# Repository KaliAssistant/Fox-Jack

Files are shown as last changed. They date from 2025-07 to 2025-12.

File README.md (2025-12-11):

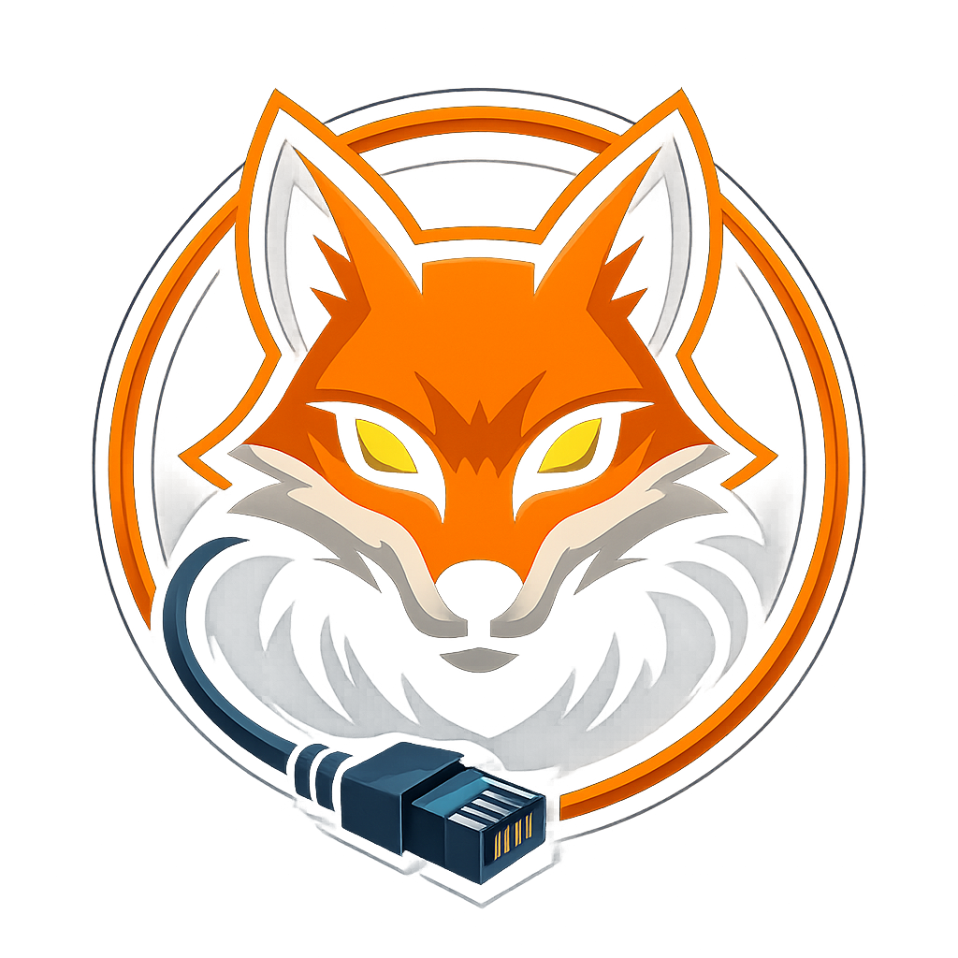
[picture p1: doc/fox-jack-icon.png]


# Fox-Jack
> Portable social-engineering LAN tool for automated payloads and wired audits — based on Luckfox Pico Max

## About

**Fox-Jack** is a low-cost, DIY social engineering LAN implant inspired by the Hak5 SharkJack.  
Designed for payload delivery, opportunistic wired auditing, and SE engagements, it features DIP-switch mode control, RGB LED feedback, and USB gadget interfaces — all powered by the **Luckfox Pico Max (RV1106G3)**.

### Features

* USB gadget function: **RNDIS** over USB
* 100 Mbps onboard **GMAC** Ethernet
* Based on **Luckfox Pico Max (RV1106G3)**
* Optional **open-source extension board PCB**:

  * 300mAh LiPo battery support (\~1–2hr uptime, longer with bigger battery)
  * **NeoPixel RGB LED** status indicator
  * **2-position DIP switch** to select payloads
* Optional **3D printable cases**
* Rootfs: **Buildroot**
* Boot: **SD card**
* U-Boot: **Luckfox official SDK**

---

## Repository Contents

* 🧰 **Luckfox Pico Official SDK**
* 🔨 **Image build scripts**
* 🧱 **3D-printable case designs**
* 🗒 **Optional extension board**:

  * KiCad project
  * Gerber files
  * BOM

---

## Parts List

| Item | Qty | Link |
| --- | --- | ---- |
| Luckfox Pico MAX (256 MB RAM version only) | 1 | [Amazon](https://a.co/d/7qTUaEF) |
| M2x0.4 Heat-Set Thread Insert (D3×H2.5) | 2 | [Amazon](https://a.co/d/6mJeA5C) |
| M2x0.4 Heat-Set Thread Insert (D3×H2) | 2 | [Amazon](https://a.co/d/6mJeA5C) |
| M2x0.4 Ultra-Low Head Torx Screws (3mm) | 2 | [Amazon](https://a.co/d/fiHYJ7t) |
| M2x0.4 Hex Socket Head Cap Screws (10mm) | 2 | [Amazon](https://a.co/d/4TCJOGo) |
| DIP Switch 1 Positions | 1 | [Amazon](https://a.co/d/8rEHPwg) |
| 302040 Lipo 3.7v battery | 1 | [Amazon](https://amzn.eu/d/auT4PZT) |

> [!NOTE]
> 🔧 PCB & BOM: all files in the `pcb/` directory

---

## Required Tools

* 28 AWG electrical wire
* Soldering tools:

  * Solder
  * Solder iron
  * Solder paste
  * Solder flux
  * Hot air gun (for SMD components on extension board)

---

## Fox-Jack EXT Board

#### Assembly Notes: [README](./pcb/README.md)

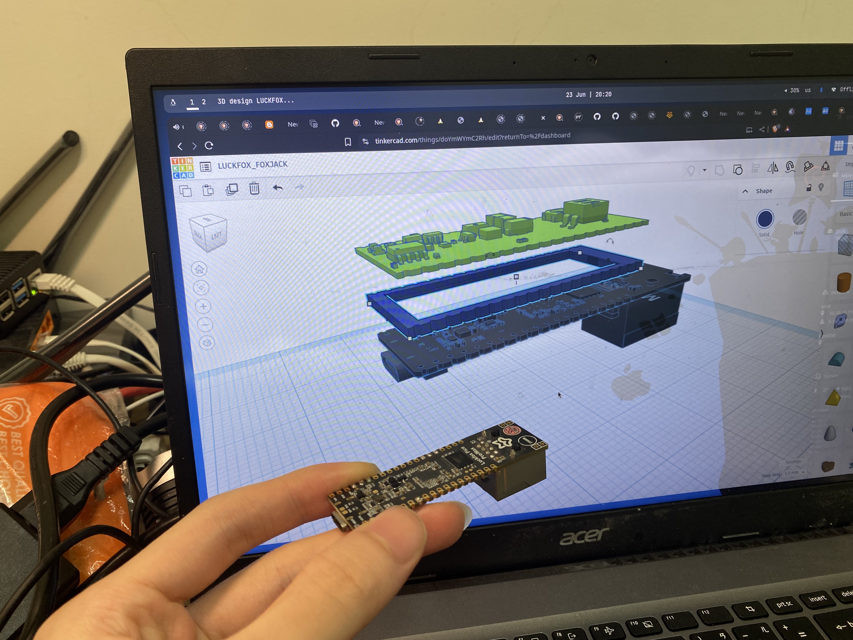
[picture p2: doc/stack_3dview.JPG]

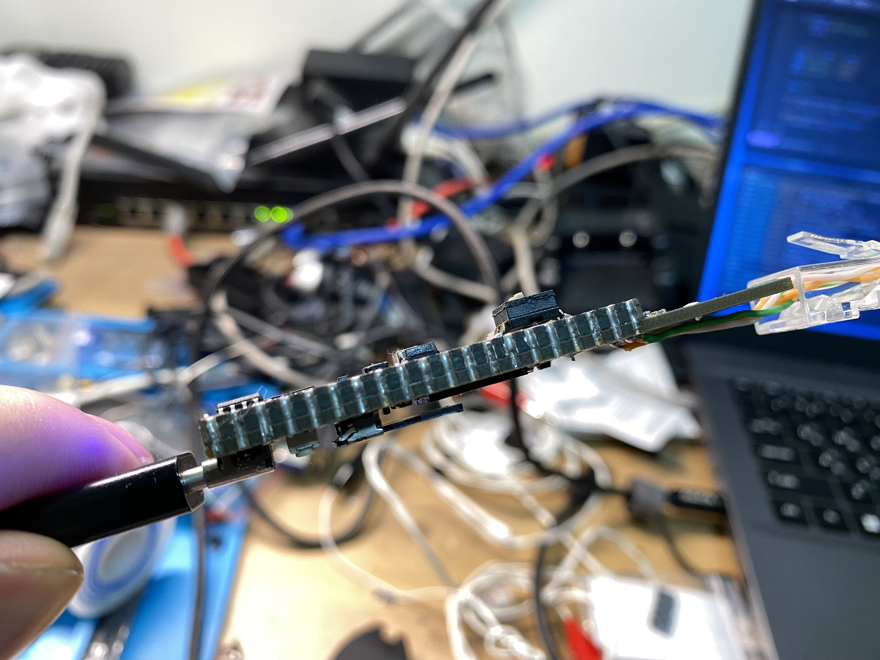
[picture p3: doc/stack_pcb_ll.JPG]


---

## 3D printable cases

#### see: [README](./3dp/README.md)

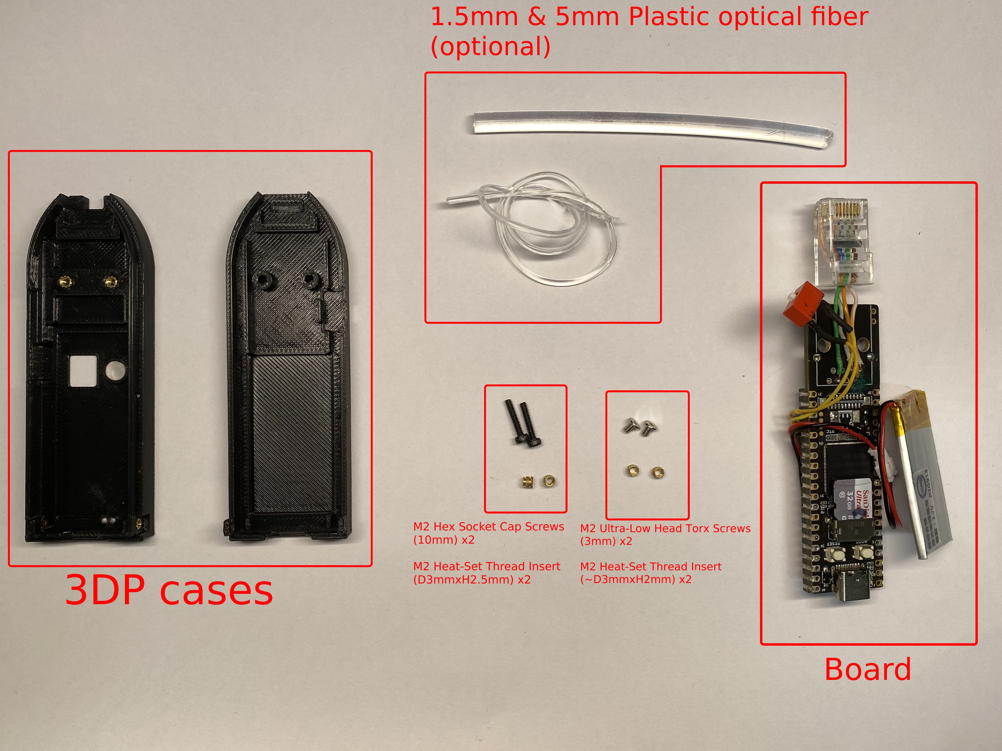
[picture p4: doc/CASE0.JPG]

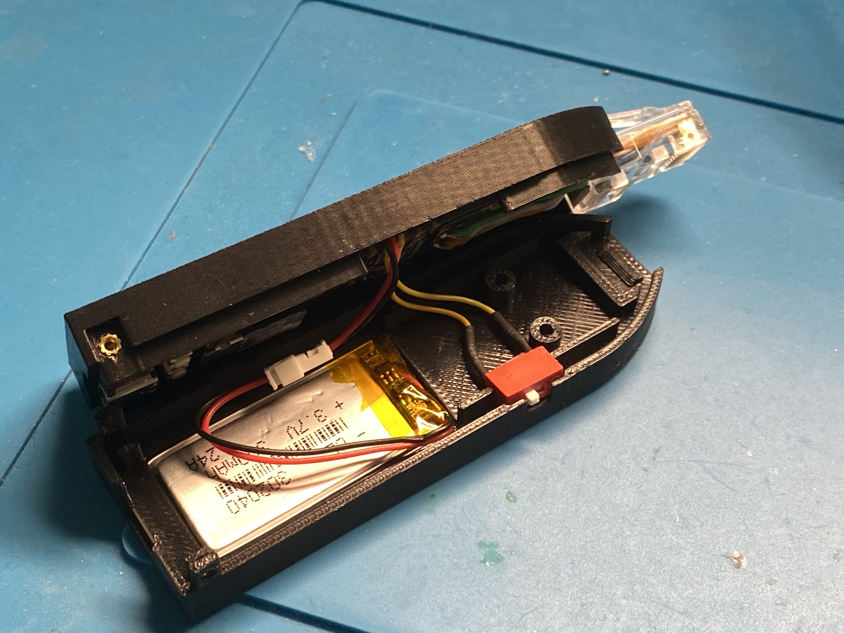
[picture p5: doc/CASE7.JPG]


---

## Build Instructions

1. Create a Debian/Ubuntu/Kali (or other Debian-based) Linux environment
   *(You can use a VM or physical machine — author uses a Debian laptop)*

2. Install required dependencies:

   ```bash
   sudo ./dep.sh
   sudo apt update
   sudo apt install -y docker.io kconfig-frontends make cmake automake autoconf libtool libtool-bin rsync
   ```
   
3. Clone the repository:

   ```bash
   git clone https://github.com/KaliAssistant/Fox-Jack.git
   ```

4. Navigate into the repo:

   ```bash
   cd Fox-Jack
   ```

5. Run the build script:

   ```bash
   sudo ./build.sh all
   ```

   You will see the SDK's *lunch menu*:

   ```
   You're building on Linux
   Lunch menu...pick the Luckfox Pico hardware version:
   [4] RV1106_Luckfox_Pico_Pro_Max
   ...
   Which would you like? [default: 0]: 4

   Lunch menu...pick the boot medium:
   [0] SD_CARD
   Which would you like? [default: 0]: 0

   Lunch menu...pick the system version:
   [0] Buildroot
   Which would you like? [default: 0]: 0
   ```

> [!NOTE]
> ✅ Just enter `4 / 0 / 0` — **only Luckfox Pico Max** is supported currently.

---

## Config Options

You can tweak build options using the following:

* **Buildroot menuconfig**:

  ```bash
  sudo ./build.sh luckfox buildrootconfig
  ```
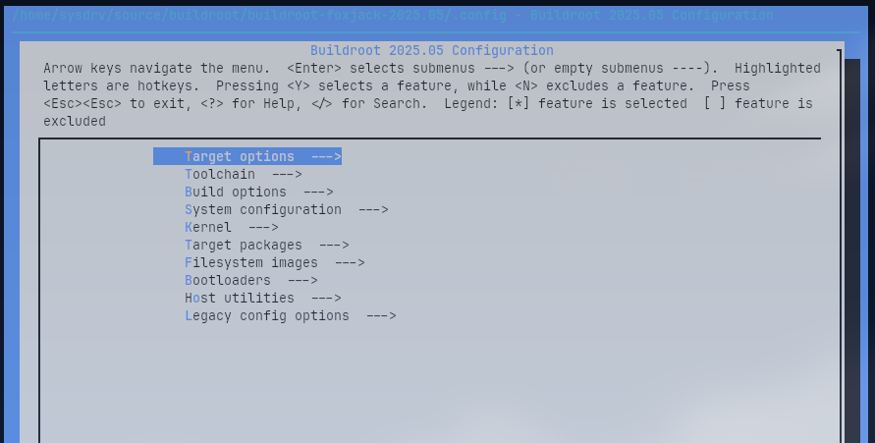
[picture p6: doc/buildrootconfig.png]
  

* **Kernel menuconfig**:

  ```bash
  sudo ./build.sh luckfox kernelconfig
  ```
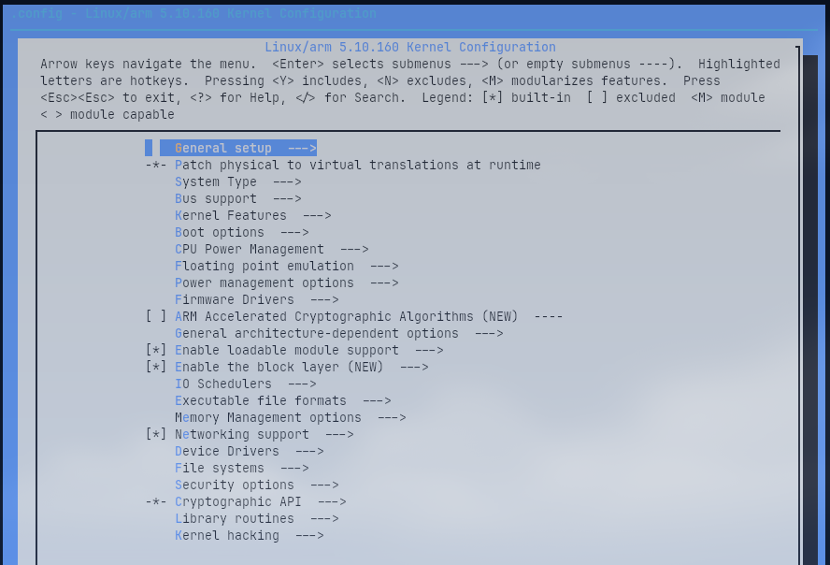
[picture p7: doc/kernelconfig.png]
  

* **Foxjack extra config (e.g., SSH key, services)**:

  ```bash
  sudo ./build.sh foxjackconfig
  ```
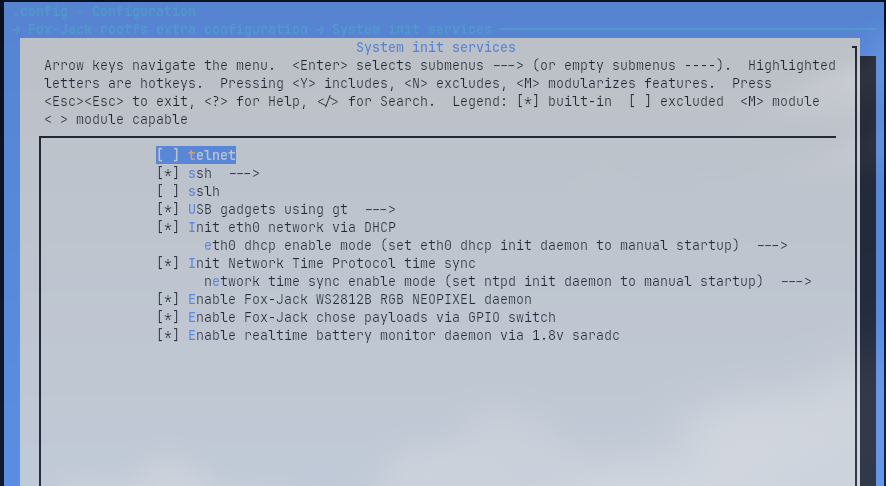
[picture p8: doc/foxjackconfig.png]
  

> [!NOTE]
> **Security Note:**
> Default root password is `foxjack`, but **SSH password login is disabled** (`PermitRootLogin prohibit-password`) for security.
> Add your public key via `foxjackconfig`.
> If you need password login, modify `/etc/ssh/sshd_config` in rootfs manually.

To access via **USB RNDIS**, make sure your host PC has a static IP in the same subnet as defined in `foxjackconfig`.

---

## Flashing to SD Card

Once the build is complete, flash the image:

```bash
sudo ./build.sh sdflash
```

You'll see:

```
WARNING: Check the SD card dev path! blkenvflash can overwrite your system drives!
Enter your SD card dev path (/dev/sxx)... >
```

> [!WARNING]
> **Be careful!** Enter the correct SD card device path to avoid overwriting your OS drive.

---

## Run Modes (Payload Selection)

Fox-Jack supports 4 modes, selected via a 2-position DIP switch:

| Mode | SW1 | SW2 | Description |
| --- | --- | --- | --- |
| 0 (debug) | 0 | 0 | Dev/debug mode |
| 1 | 1 | 0 | Payload 1 |
| 2 | 0 | 1 | Payload 2 |
| 3 | 1 | 1 | Payload 3 |

Read via GPIO:

```c
#define SW1_PIN 67  // gpio2_a3_d (pin 27)
#define SW2_PIN 66  // gpio2_a2_d (pin 26)
```

---

### Debug Mode Details

In **debug mode** (SW1=0, SW2=0):

* USB gadget provides **RNDIS Ethernet** **+ Mass Storage**
* Payloads can be edited directly from host PC
* **LOOT** (results, passwords, hashes) is saved in:

  ```
  <UMS>/loot/
  ```
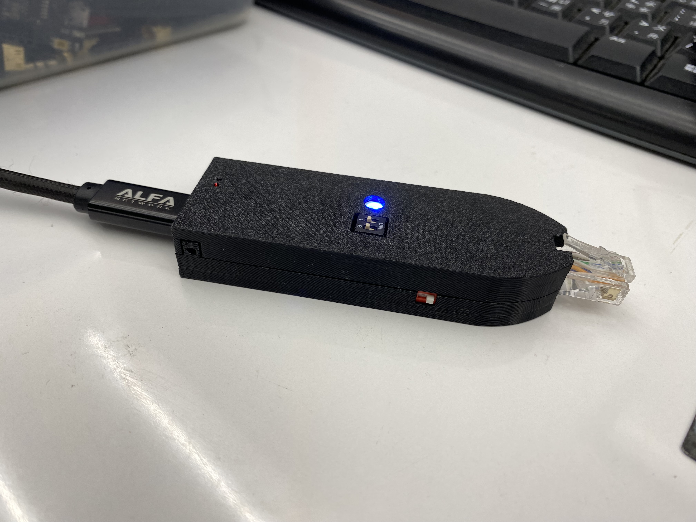
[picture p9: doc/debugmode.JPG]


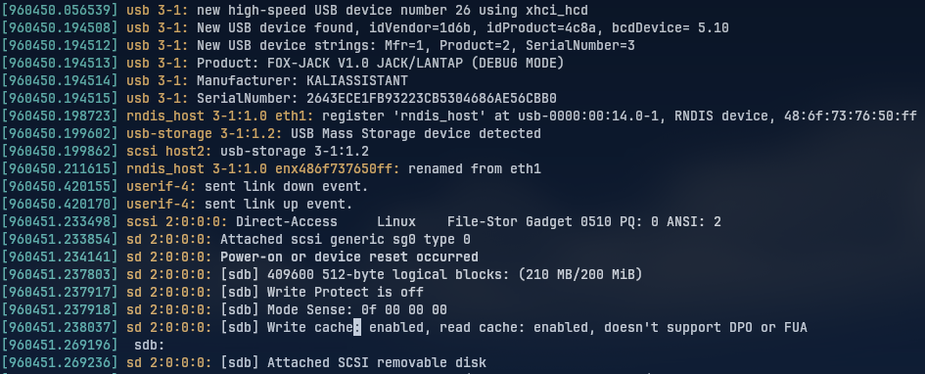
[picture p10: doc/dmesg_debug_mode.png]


---

## Payload Examples

#### see [README](./payload_examples/README.md)

Payload filenames must follow this format:

```
E????-name.payload
```

* `E????` is a 4-digit payload ID (e.g., `E0000`)
* `name` is a short, descriptive label

**Example:**

```
E0000-arp-scan.payload
```

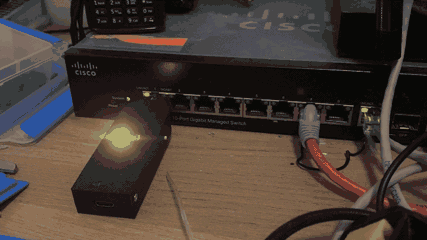
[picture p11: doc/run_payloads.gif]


---

## Disclaimer

**Fox-Jack** is intended for authorized security testing, educational, and research purposes only.  
Use of this device without explicit permission on networks or systems you do not own or have authorization to test is illegal and unethical.  
The author and contributors are not responsible for any misuse or damage caused by this tool.  
Please ensure you comply with all applicable laws and obtain proper consent before deployment.

---

## License

Fox-Jack is open-source and released under the **GNU General Public License v3.0 (GPLv3)**.
You are free to use, modify, and redistribute under the terms of this license.

See the [`LICENSE`](./LICENSE) file for full details.

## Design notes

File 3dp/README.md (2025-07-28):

#  3D Printed Case Guide – *Fox-Jack*

This folder contains the 3D printable files for the **Fox-Jack** case.

Use both **top** and **bottom** case designs with **M2 heat-set inserts** and **screws** to assemble.

---

## Step 0. Prepare These Items

| Item | Qty | Link |
| --- | --- | -----|
| M2x0.4 Heat-Set Thread Insert (D3×H2.5) |  2  | [Amazon](https://a.co/d/6mJeA5C)
| M2x0.4 Heat-Set Thread Insert (D3×H2) |  2  | [Amazon](https://a.co/d/6mJeA5C)
| M2x0.4 Ultra-Low Head Torx Screws (3mm) |  2  | [Amazon](https://a.co/d/fiHYJ7t)
| M2x0.4 Hex Socket Head Cap Screws (10mm) |  2  | [Amazon](https://a.co/d/4TCJOGo)
| Plastic optic fiber (1.2~1.5mm, optional)  |  1  | [Amazon](https://a.co/d/c6yUWJW)
| Plastic optic fiber (5mm, optional) |  1  | [Amazon](https://a.co/d/c6yUWJW)



---

##  Step 1. Print the Cases

You can use:

- Supported Materials: PLA+, PETG, ABS

> [!NOTE]
> Do **not** use **non-FDM** printers (e.g. resin printers), since heat-set inserts won’t work with those materials.

---

## Step 2. Insert Heat-Set Inserts

- You can use a soldering iron or a dedicated tool
- Gently press the inserts into place while heating

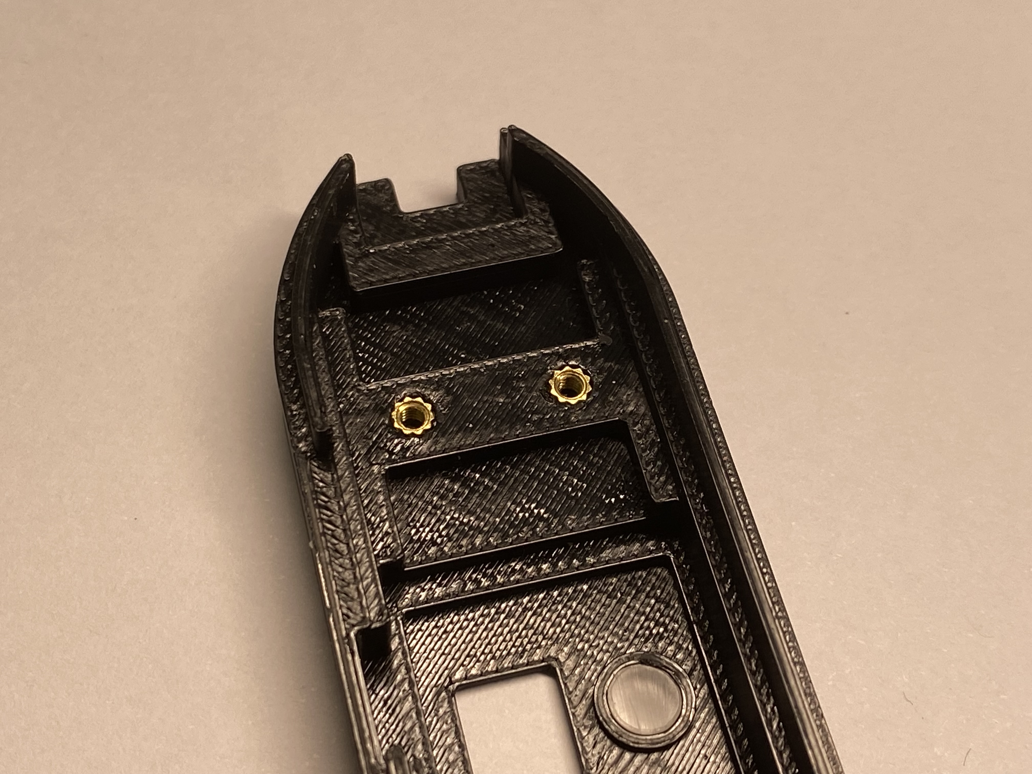
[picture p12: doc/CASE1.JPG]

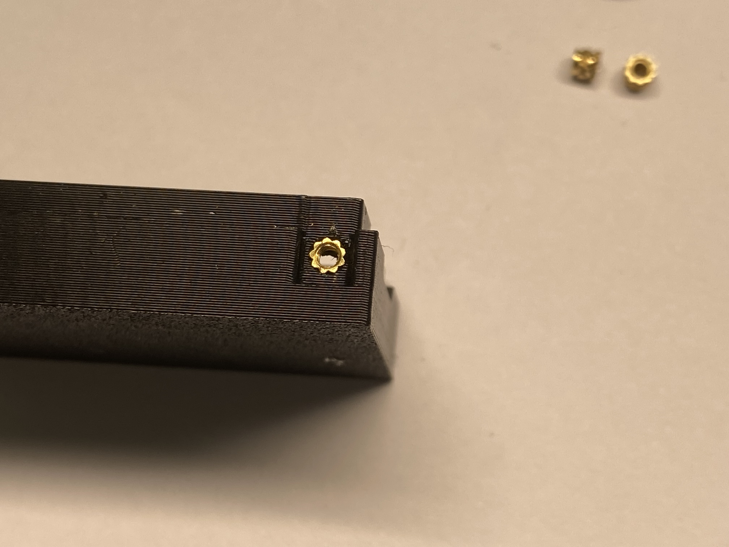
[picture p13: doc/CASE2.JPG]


---

## Step 3. Add Fiber to LED Holes (Optional, But Looks Awesome)

- Plastic fiber makes LED glow look much better
- Push fiber into LED holes

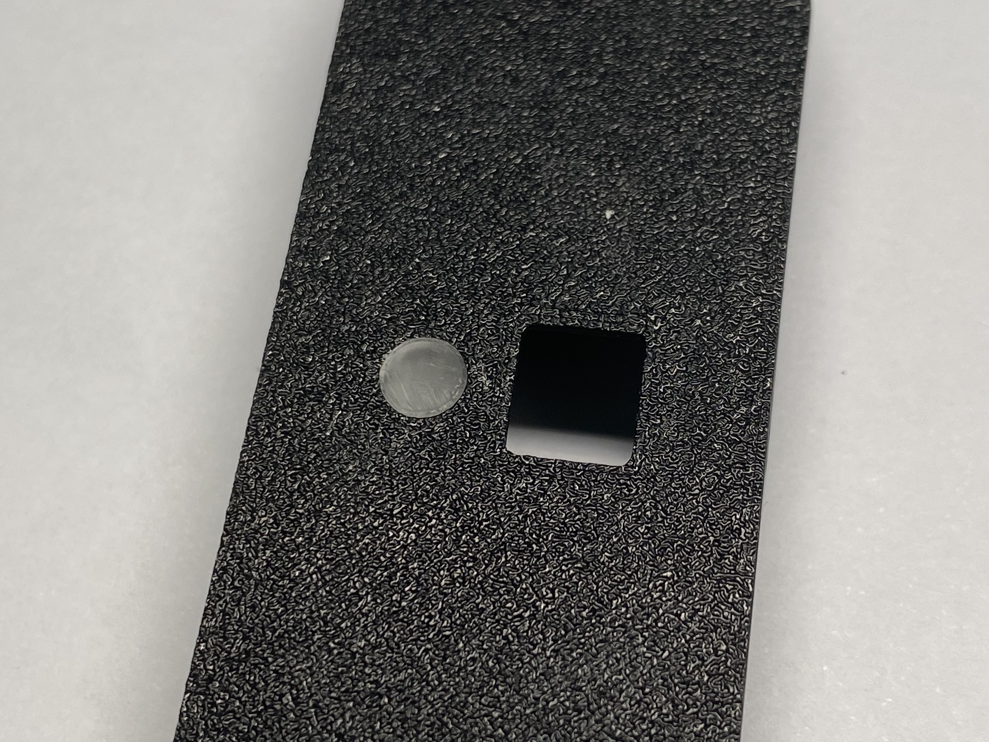
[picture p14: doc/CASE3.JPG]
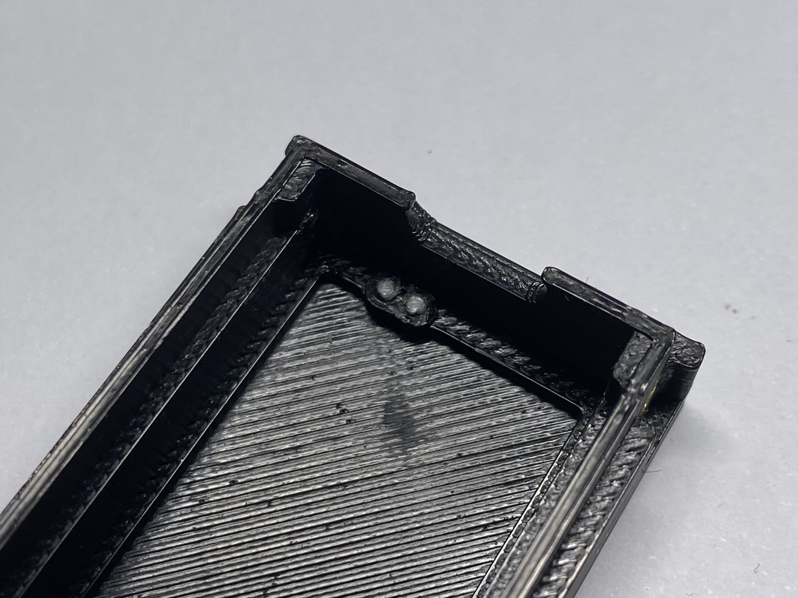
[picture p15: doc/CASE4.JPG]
 
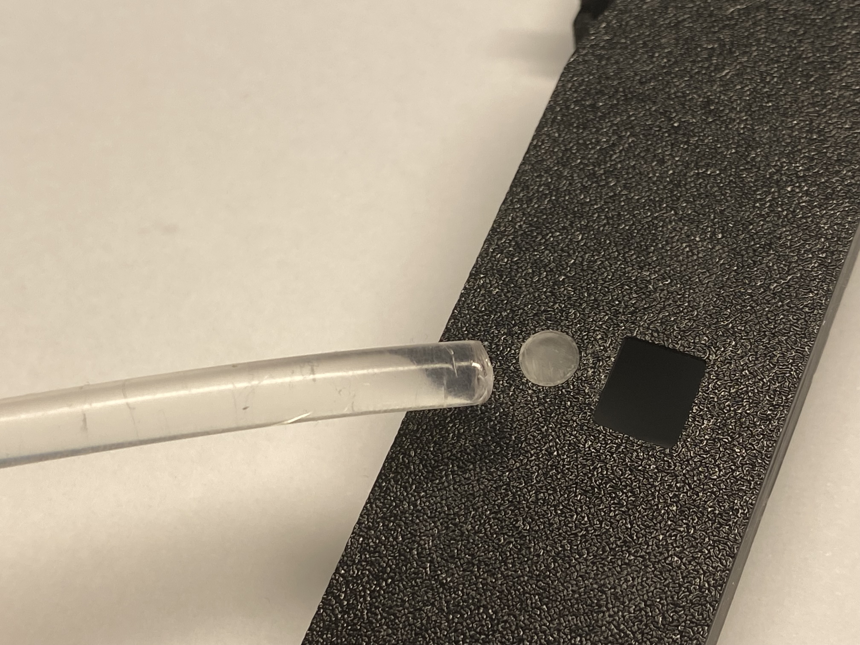
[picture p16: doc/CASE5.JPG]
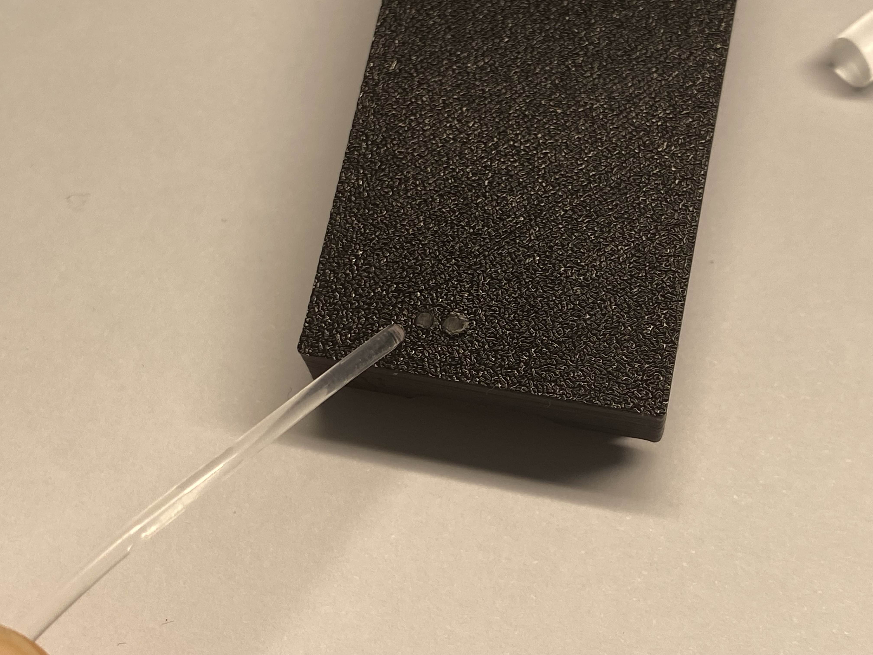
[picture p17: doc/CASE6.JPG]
 

---

## Step 4. Final Assembly

- Align top and bottom case
- Use M2 screws to secure
- Don’t overtighten


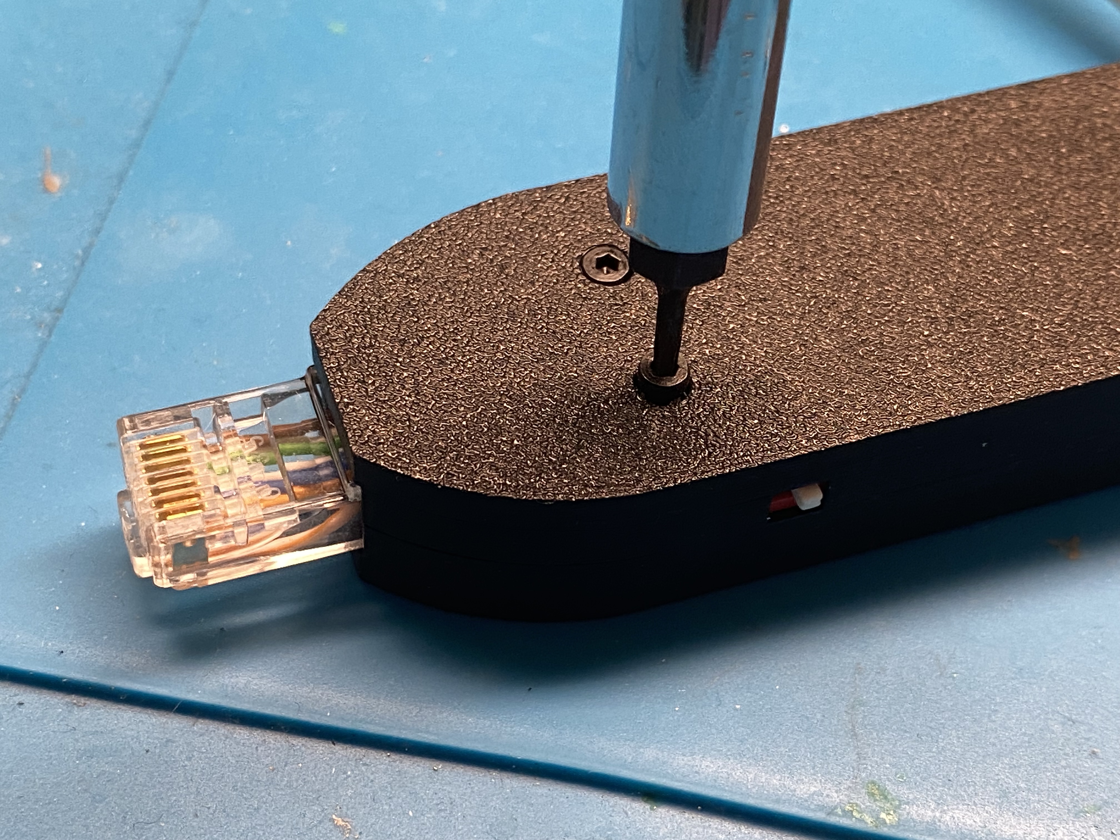
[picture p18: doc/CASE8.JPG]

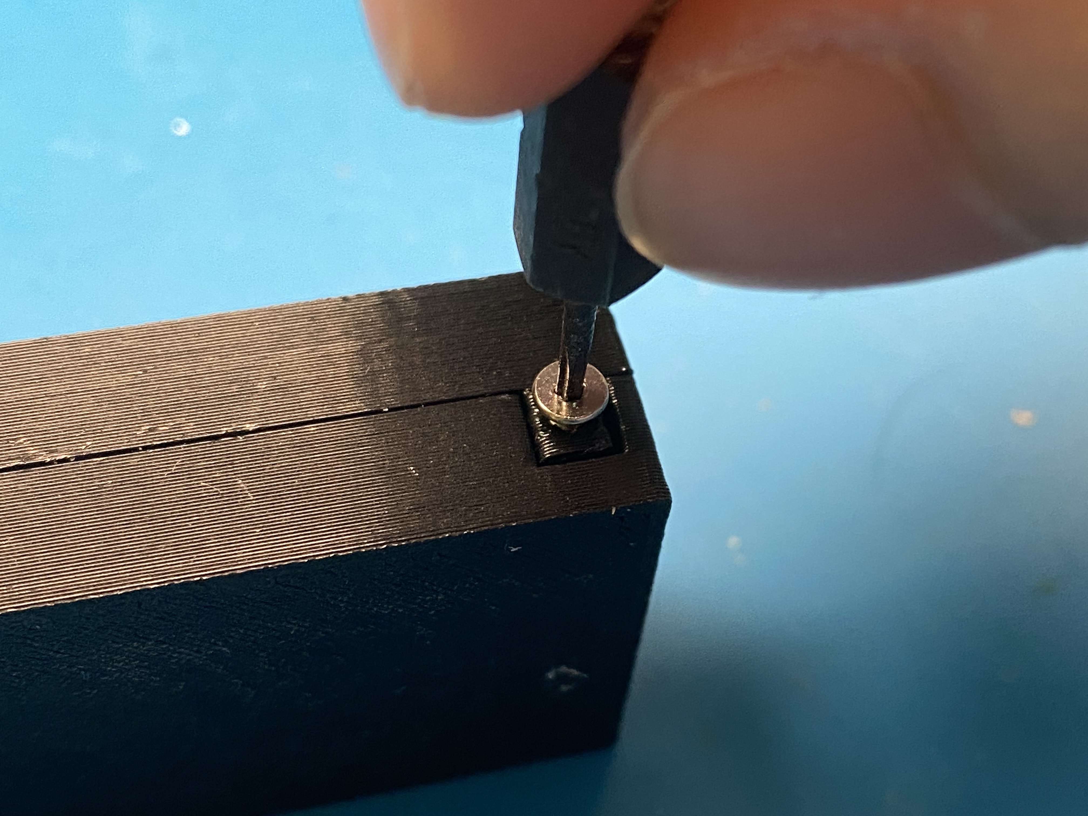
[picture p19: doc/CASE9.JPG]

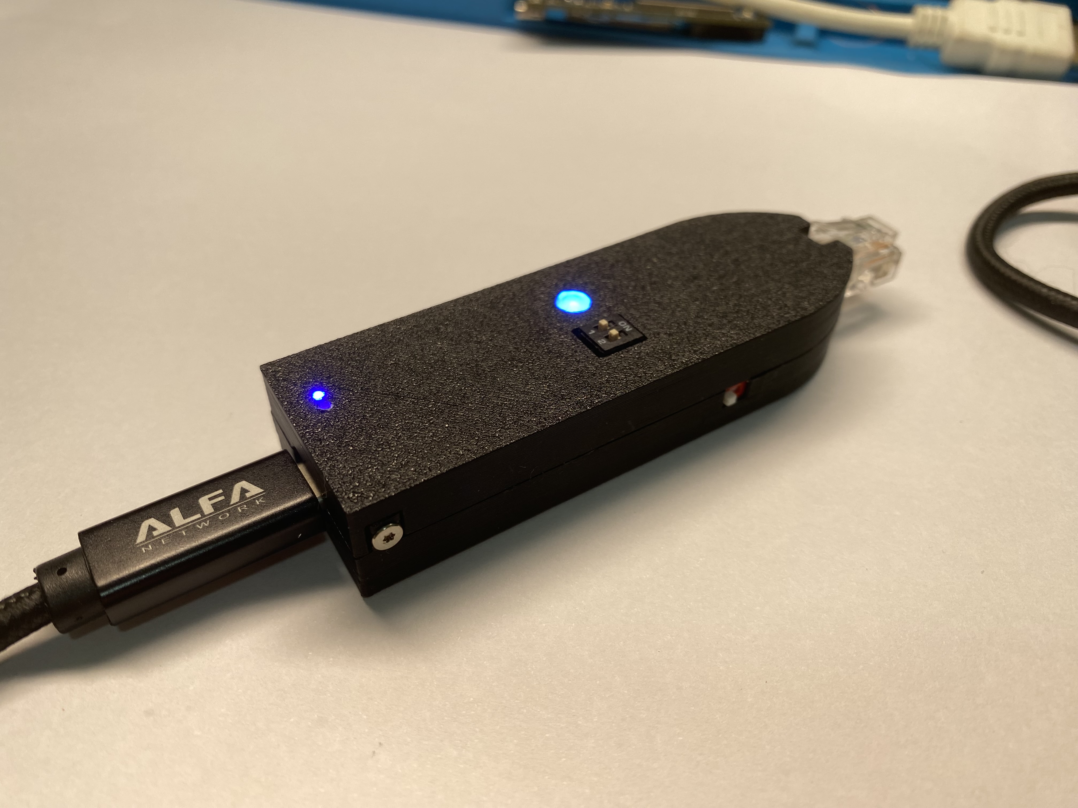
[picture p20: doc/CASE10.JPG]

---

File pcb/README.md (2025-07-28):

# FOX-JACK\_EXT\_BOARD

This directory contains the open-source **extension board** for the [Fox-Jack](https://github.com/KaliAssistant/Fox-Jack) project.

Designed with a **stacked PCB layout** inspired by modular smartphones (like iPhones), the board achieves a **compact**, **robust**, and **DIY-friendly** assembly with the **Luckfox Pico Max**.

Top View
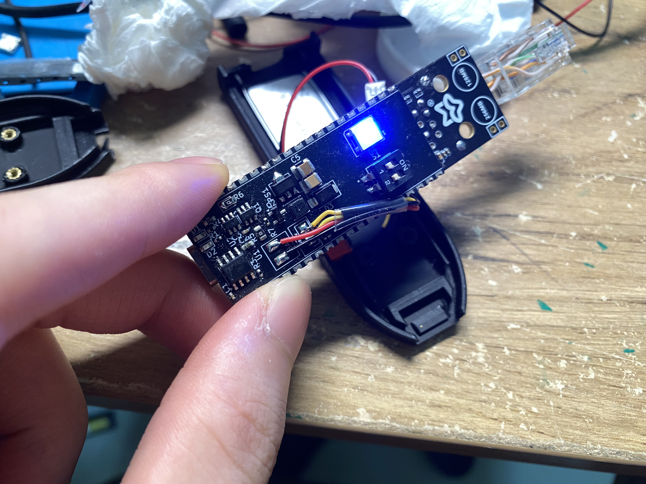
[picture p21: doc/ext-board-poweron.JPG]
Powered On


---

## Board Structure

The extension board is made up of **two stacked PCBs**:

### 1. `FOX-JACK_EXT_BOARD_TOP`

* Primary functional PCB
* PCB thickness: **0.8mm**
* Hosts core components: battery management, WS2812 (NeoPixel), DIP switch, etc.

### 2. `FOX-JACK_EXT_BOARD_MID`

* Acts as a **mechanical connector** and **base shim**
* PCB thickness: **1.6mm**
* Designed to fit perfectly between the `TOP` board and the **Luckfox Pico Max**
* Provides mechanical rigidity and solder alignment

> [!NOTE]
>  This stacked layout allows professional-looking compact integration at minimal cost and effort.

---

## Assembly Notes

> [!NOTE]
> Soldering requires careful thermal profiling!

* **Top Board (`TOP`)**

  * Use **high-temperature solder paste** (e.g., Sn63/Pb37 or SAC305)

* **Mid Board (`MID`)**

  * Use **low-temperature solder paste** (e.g., Sn42/Bi58) for the mechanical + electrical bridge with the Pico board
  * Helps avoid reflowing the `TOP` board during final reflow


---

## Battery Info

* Recommended: **Li-ion 3.7V 300mAh**
* Model: **302040**
* Chosen to fit snugly inside the 3D-printed case in this repo

---

## ADC Voltage Measurement

If you want to **read battery voltage** using the **Pico’s ADC**:

* Remove **R57** on the **Luckfox Pico Max PCB**
* (R57 is a **10K ±5% pull-up** resistor that affects accurate voltage reading)
* See https://github.com/LuckfoxTECH/luckfox-pico/issues/174

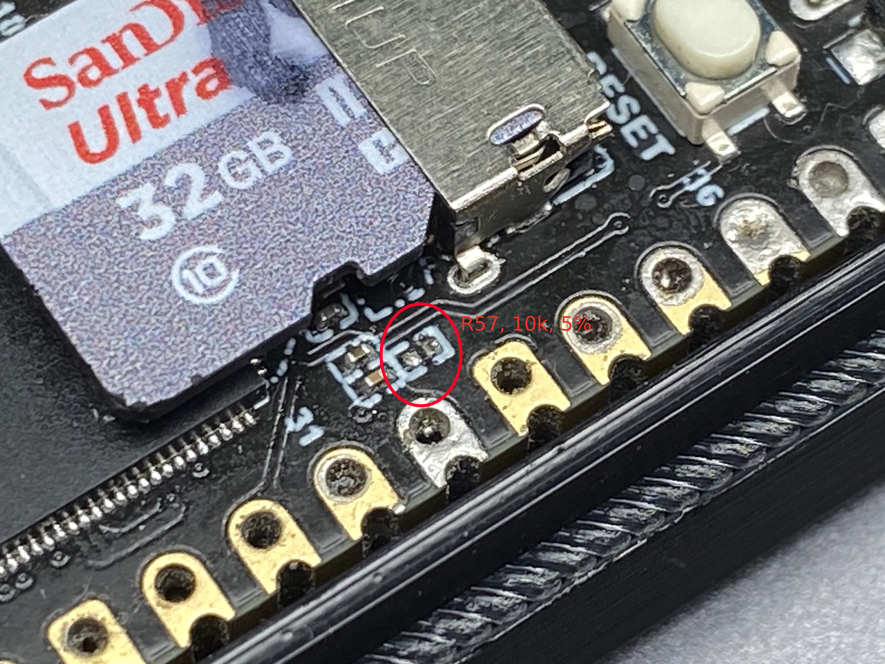
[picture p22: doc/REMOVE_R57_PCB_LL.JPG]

---

## Compatibility with 3D-Printed Case

To fit the extension + Pico board into the provided **3D-printed case**, perform the following hardware mods:

1. **Remove** the following components from the Pico:

   * **RJ45 Ethernet socket**
   * **CSI Camera connector**
   * **RTC battery holder**

2. **Modify Ethernet Cable**:

   * Cut and strip a short **4P (or 8P)** RJ45 cable
   * Remove filler and outer jacket
   * Solder directly to the Pico’s Ethernet pads
   * 4P is enough for **100 Mbps** **(rv1106g3 gmac only support 100Mbps phy)**


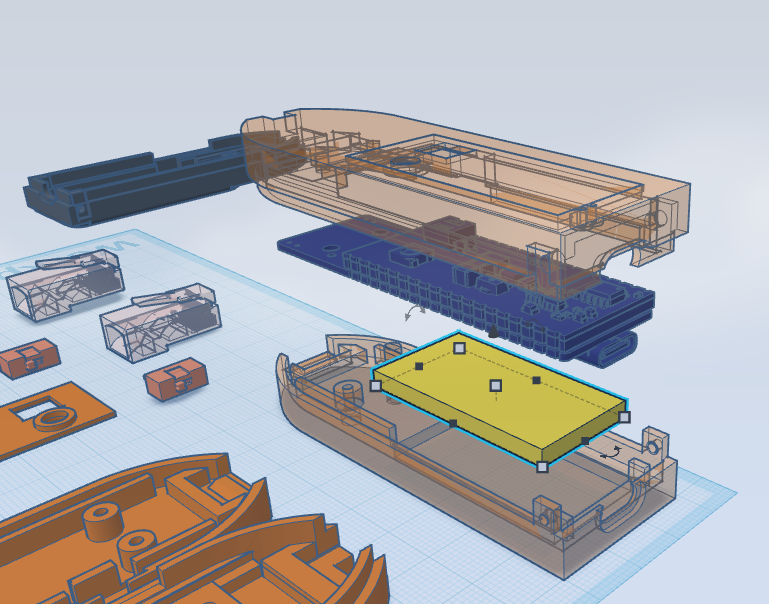
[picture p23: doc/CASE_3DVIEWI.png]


---

## Files Included

* ✅ KiCad project files (`.kicad_pcb`, `.sch`, etc.)
* ✅ Gerber + drill files (for fabrication)
* ✅ BOM (Bill of Materials)
* ✅ Assembly guidelines
* ✅ 3D models and printable case (`.stl`, in [<repo_dir>/3dp](../3dp/))

---

## PCB Manufacturing Notes (e.g., JLCPCB)

When ordering:

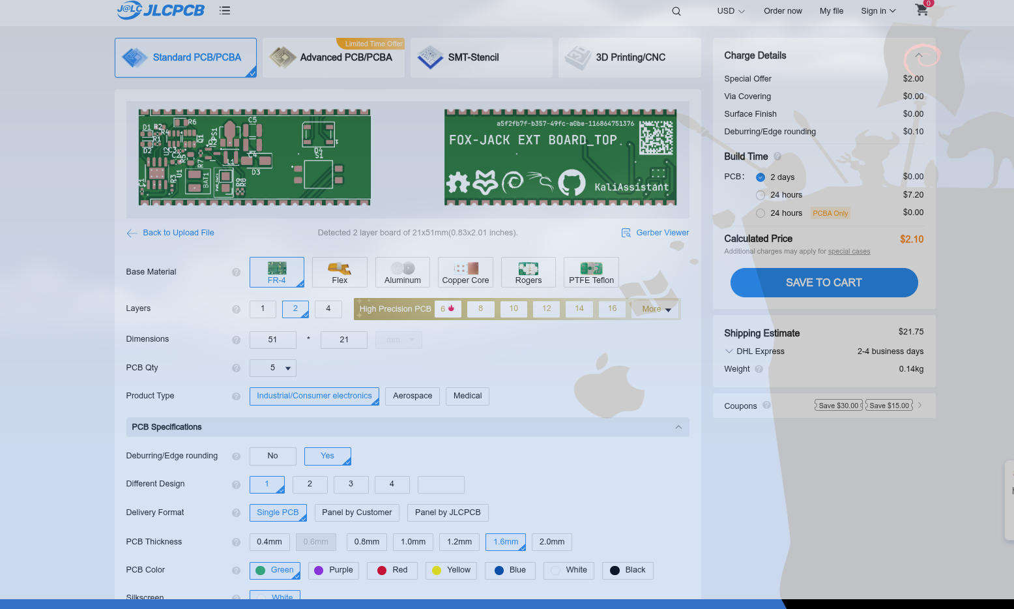
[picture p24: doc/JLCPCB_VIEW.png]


* ✅ Use **standard PCB processing** (no special options)
* ❗️ **Do NOT enable “Castellated Holes”** — leave this option **unchecked**
* ✅ This keeps the board cost around **\$4 USD**
* ❌ Enabling Castellated Holes may raise the quote to **\$40+ USD**, unnecessarily

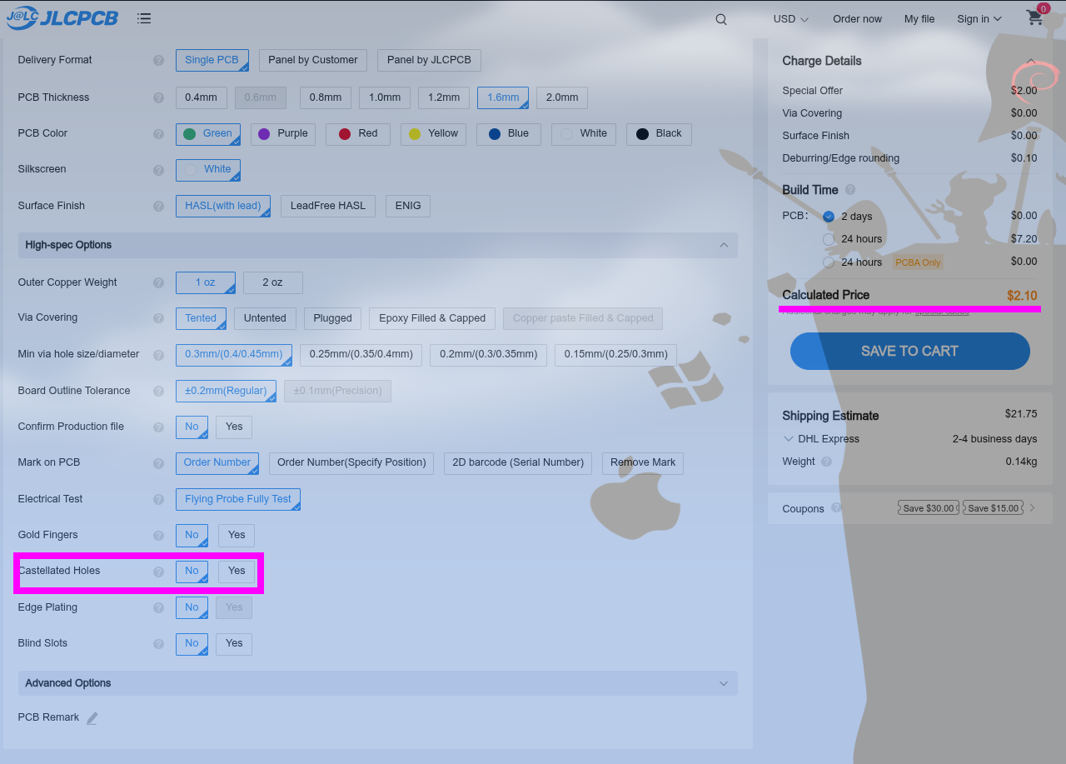
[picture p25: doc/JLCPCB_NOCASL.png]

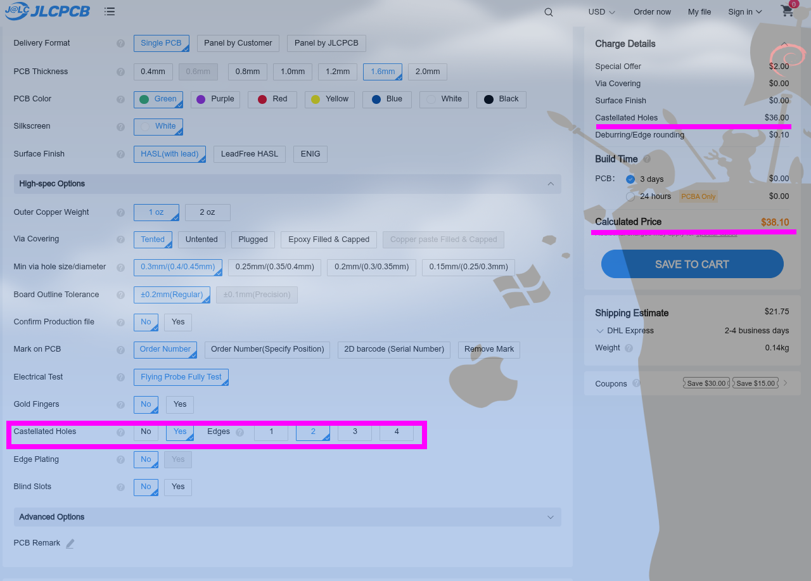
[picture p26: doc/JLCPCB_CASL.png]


> [!NOTE]
> This design **does not use true castellated holes**.
> Instead, it relies on **DIY-style side solder bridging** using exposed edge pads on a regular PCB.
> This approach is **cost-efficient**, **strong enough**, and perfectly suited for **DIY assembly** — no need for expensive edge plating.

---

## License

Licensed under **GNU GPLv3**.
Feel free to **use**, **study**, **modify**, and **share** under the same license.

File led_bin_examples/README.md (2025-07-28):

# LED BIN EXAMPLES

This directory contains example **SHM writer binary files** for the Fox-Jack EXT board’s **WS2812B RGB LED**.

---

## File Format

Each `.bin` file is a sequence of RGB frames in **binary format**:

```bash
printf "\xRR\xGG\xBB\xRR\xGG\xBB..." > led.bin
```

* Each **frame = 3 bytes** (Red, Green, Blue)
* Multiple frames can be appended for animations

---

## Runtime Integration

These binary files are consumed by the `shmled` tool, which writes to a shared memory segment read by the `ws2812d` daemon.

### Device Path:

`/dev/shm/led_rgb` — shared memory backend read by the WS2812 RGB LED daemon

---

## Example Usage

```bash
shmled -l -i led.bin -s 10000
```

* `-l` → enable loop mode
* `-i led.bin` → input binary animation file
* `-s 10000` → delay 10,000 microseconds per frame

---

## Full Command-Line Options

```
$ shmled -h
shmLED - WS2812 RGB NEOPIXEL SHM WRITER

Usage: shmled -c #RRGGBB -i <rgb bin file input> [-l -i|-b|-d|-r] [-s µs]

-c :   #RRGGBB, RGB hex color
-i :   <input.bin>, binary RGB input file (\xRR\xGG\xBB ...)
-l :   Loop mode:
       -b : blink
       -d : fade
       -r : rainbow
       -i : loop input file
-s :   Delay in microseconds per frame
-h :   Show this help message
```

---

## Notes

* Compatible with **any WS2812B** device wired to `/dev/led_rgb`
* `shmled` can be used for **static colors**, **predefined animations**, or **custom loops**
* The example `.bin` files here are ready to use — or you can generate your own with simple scripts

---

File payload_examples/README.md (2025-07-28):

# FOX-JACK Payload Examples

This directory contains example payloads for **FOX-JACK**.

## Filename Format

Payload filenames must follow this format:

```
E????-name.payload
```

* `E????` is a 4-digit payload ID (e.g., `E0000`)
* `name` is a short, descriptive label

**Example:**

```
E0000-arp-scan.payload
```

## How to Use

1. Copy or write your payload file into one of the following directories on the UMS disk:

   ```
   <UMS_DISK>/payloads/mod1.d/
   <UMS_DISK>/payloads/mod2.d/
   <UMS_DISK>/payloads/mod3.d/
   ```

   These correspond to FOX-JACK’s Mode 1, 2, and 3 (switch positions).

2. Each payload must be a valid executable script (typically Bash) and will run automatically when that mode is selected.

## ⚠️ Notes

* GNU `coreutils` is **not supported currently**, because its build requires disabling **Y2038** support in Buildroot, which is not recommended.
* Use **BusyBox-compatible** commands in your scripts for best compatibility with FOX-JACK’s minimal environment.

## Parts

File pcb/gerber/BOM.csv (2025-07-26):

Index | LCSC# | MPN | Manufacturer | Package | Customer # | Description | RoHS | Quantity | MOQ | Multiple | Unit Price($) | Extended Price($) | Product Link
1 | C236798 | ME2108A50PG | MICRONE | SOT-89-3 | PS1 | Boost 5V 400mA 900mV~6.5V SOT-89-3 DC-DC Converters ROHS | yes | 5 | 5 | 5 | 0.0680 | 0.34 | https://lcsc.com/product-detail/dc-dc-converters_microne-me2108a50pg_C236798.html
2 | C21190 | 0603WAF1001T5E | UNI-ROYAL | 0603 | R4 | 100mW Thick Film Resistor 75V ±100ppm/℃ ±1% 1kΩ 0603 Chip Resistor - Surface Mount ROHS | yes | 100 | 100 | 100 | 0.0011 | 0.11 | https://lcsc.com/product-detail/chip-resistor-surface-mount_uni-royal-0603waf1001t5e_C21190.html
3 | C83852 | SS14 | onsemi | SMA(DO-214AC) | D3 | 40V 500mV@1A 1A SMA(DO-214AC) Schottky Diodes ROHS | yes | 5 | 5 | 5 | 0.1319 | 0.66 | https://lcsc.com/product-detail/schottky-diodes_onsemi-ss14_C83852.html
4 | C281774 | RT0402BRD0714K7L | YAGEO | 0402 | R8 | 62.5mW Thin Film Resistor 50V ±25ppm/℃ ±0.1% 14.7kΩ 0402 Chip Resistor - Surface Mount ROHS | yes | 50 | 50 | 50 | 0.0195 | 0.98 | https://lcsc.com/product-detail/chip-resistor-surface-mount_yageo-rt0402brd0714k7l_C281774.html
5 | C15127 | AO3401A | AOS | SOT-23 | Q2 | 30V 85mΩ@2.5V,2.5A 1.3V@250uA 1 P-Channel SOT-23 MOSFETs ROHS | yes | 10 | 10 | 10 | 0.0602 | 0.60 | https://lcsc.com/product-detail/mosfets_aos-ao3401a_C15127.html
6 | C19702 | CL10A106KP8NNNC | Samsung Electro-Mechanics | 0603 | C2 | 10V 10uF X5R ±10% 0603 Multilayer Ceramic Capacitors MLCC - SMD/SMT ROHS | yes | 20 | 20 | 20 | 0.0058 | 0.12 | https://lcsc.com/product-detail/multilayer-ceramic-capacitors-mlcc-smd-smt_samsung-electro-mechanics-cl10a106kp8nnnc_C19702.html
7 | C60490 | RC0402FR-0710KL | YAGEO | 0402 | R7,R9 | 62.5mW Thick Film Resistor 50V ±100ppm/℃ ±1% 10kΩ 0402 Chip Resistor - Surface Mount ROHS | yes | 100 | 100 | 100 | 0.0006 | 0.06 | https://lcsc.com/product-detail/chip-resistor-surface-mount_yageo-rc0402fr-0710kl_C60490.html
8 | C17477 | 0805W8F0000T5E | UNI-ROYAL | 0805 | R6 | 125mW Thick Film Resistor 150V ±800ppm/℃ ±1% 0Ω 0805 Chip Resistor - Surface Mount ROHS | yes | 100 | 100 | 100 | 0.0017 | 0.17 | https://lcsc.com/product-detail/chip-resistor-surface-mount_uni-royal-0805w8f0000t5e_C17477.html
9 | C2843785 | XL-5050RGBC-WS2812B | XINGLIGHT | SMD5050 | D4 | SMD5050 RGB LEDs(Built-in IC) ROHS | yes | 10 | 10 | 10 | 0.0490 | 0.49 | https://lcsc.com/product-detail/rgb-leds-built-in-ic_xinglight-xl-5050rgbc-ws2812b_C2843785.html
10 | C167761 | FNR3015S220MT | cjiang (Changjiang Microelectronics Tech) | SMD,3x3mm | L1 | 690mA 22uH Magnetic Shielded Inductor ±20% 680mA SMD,3x3mm Power Inductors ROHS | yes | 20 | 20 | 20 | 0.0735 | 1.47 | https://lcsc.com/product-detail/power-inductors_cjiang-changjiang-microelectronics-tech-fnr3015s220mt_C167761.html
11 | C6331180 | 2.54-2P TPGT | SHOU HAN | SMD | S1 | 2 SPST 24V Black 25mA 3,000 Cycles Slide, Rocked SMD DIP Switches ROHS | yes | 1 | 1 | 1 | 0.4163 | 0.42 | https://lcsc.com/product-detail/dip-switches_shou-han-2-54-2p-tpgt_C6331180.html
12 | C60474 | CC0402KRX7R7BB104 | YAGEO | 0402 | C1,C3 | 16V 100nF X7R ±10% 0402 Multilayer Ceramic Capacitors MLCC - SMD/SMT ROHS | yes | 100 | 100 | 100 | 0.0009 | 0.09 | https://lcsc.com/product-detail/multilayer-ceramic-capacitors-mlcc-smd-smt_yageo-cc0402krx7r7bb104_C60474.html
13 | C965799 | XL-1608SURC-06 | XINGLIGHT | 0603 | D2 | 20mA 225mcd Water Clear op View Mount 620nm~630nm Red 120° 50mW 2.3V 0603 LED Indication - Discrete ROHS | yes | 100 | 100 | 100 | 0.0032 | 0.32 | https://lcsc.com/product-detail/led-indication-discrete_xinglight-xl-1608surc-06_C965799.html
14 | C138687 | CL32B106KBJNNNE | Samsung Electro-Mechanics | 1210 | C4,C5 | 50V 10uF X7R ±10% 1210 Multilayer Ceramic Capacitors MLCC - SMD/SMT ROHS | yes | 2 | 1 | 1 | 0.1571 | 0.31 | https://lcsc.com/product-detail/multilayer-ceramic-capacitors-mlcc-smd-smt_samsung-electro-mechanics-cl32b106kbjnnne_C138687.html
15 | C382139 | TP4056 | TPOWER | ESOP-8 | U1 | 4V~6V Lithium-ion/Polymer 1 ESOP-8 Battery Management ROHS | yes | 5 | 5 | 5 | 0.0888 | 0.44 | https://lcsc.com/product-detail/battery-management_tpower-tp4056_C382139.html
16 | C17408 | 0805W8F1000T5E | UNI-ROYAL | 0805 | R5 | 125mW Thick Film Resistor 150V ±100ppm/℃ ±1% 100Ω 0805 Chip Resistor - Surface Mount ROHS | yes | 100 | 100 | 100 | 0.0019 | 0.19 | https://lcsc.com/product-detail/chip-resistor-surface-mount_uni-royal-0805w8f1000t5e_C17408.html
17 | C106235 | RC0402FR-071KL | YAGEO | 0402 | R1,R2 | 62.5mW Thick Film Resistor 50V ±100ppm/℃ ±1% 1kΩ 0402 Chip Resistor - Surface Mount ROHS | yes | 100 | 100 | 100 | 0.0006 | 0.06 | https://lcsc.com/product-detail/chip-resistor-surface-mount_yageo-rc0402fr-071kl_C106235.html
18 | C2927799 | DW01A | YONGYUTAI | SOT-23-6 | U2 | 1.5V~8V Lithium-ion/Polymer 1 SOT-23-6 Battery Management ROHS | yes | 20 | 20 | 20 | 0.0247 | 0.49 | https://lcsc.com/product-detail/battery-management_yongyutai-dw01a_C2927799.html
19 | C965807 | XL-1608UBC-04 | XINGLIGHT | 0603 | D1 | 20mA 300mcd Water Clear op View Mount 455nm~475nm Blue 120° 70mW 3.3V 0603 LED Indication - Discrete ROHS | yes | 100 | 100 | 100 | 0.0035 | 0.35 | https://lcsc.com/product-detail/led-indication-discrete_xinglight-xl-1608ubc-04_C965807.html
20 | C2909307 | FRC0402F1201TS | FOJAN | 0402 | R3 | 62.5mW Thick Film Resistor 50V ±100ppm/℃ ±1% 1.2kΩ 0402 Chip Resistor - Surface Mount ROHS | yes | 100 | 100 | 100 | 0.0005 | 0.05 | https://lcsc.com/product-detail/chip-resistor-surface-mount_fojan-frc0402f1201ts_C2909307.html
21 | C2830320 | FS8205A | TECH PUBLIC | SOT-23-6 | Q1 | 20V 9A 31.5mΩ@2.5V 1.5W 1.2V@250uA SOT-23-6 MOSFETs ROHS | yes | 10 | 10 | 10 | 0.0449 | 0.45 | https://lcsc.com/product-detail/mosfets_tech-public-fs8205a_C2830320.html

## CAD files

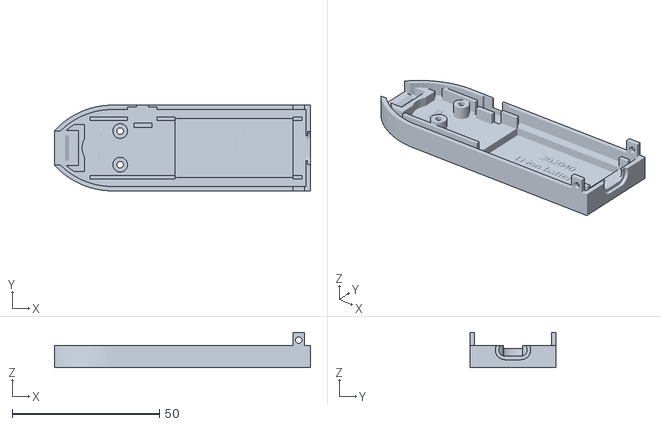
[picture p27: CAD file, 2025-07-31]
3dp/LUCKFOX_FOXJACK_BTM.stl
86.8 x 29.0 x 11.9

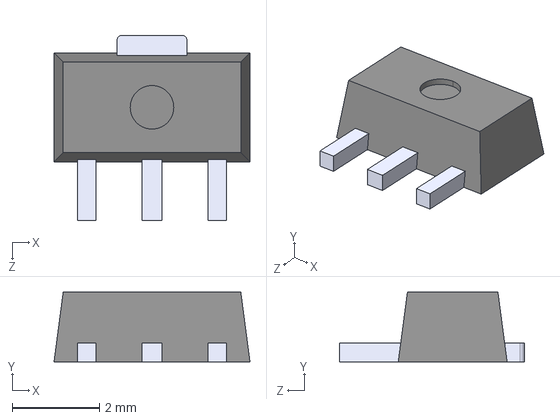
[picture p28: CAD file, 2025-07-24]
pcb/FOX-JACK_EXT_BOARD_TOP/3dmodules/ME2108A33P--3DModel-STEP-56544.STEP
4.50 x 1.60 x 4.25 mm

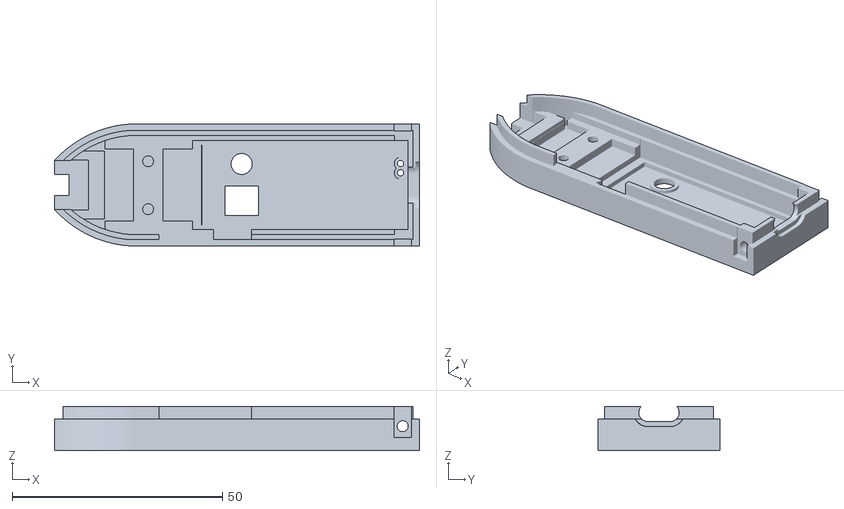
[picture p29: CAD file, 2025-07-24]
3dp/LUCKFOX_FOXJACK_TOP.stl
86.8 x 29.0 x 10.5

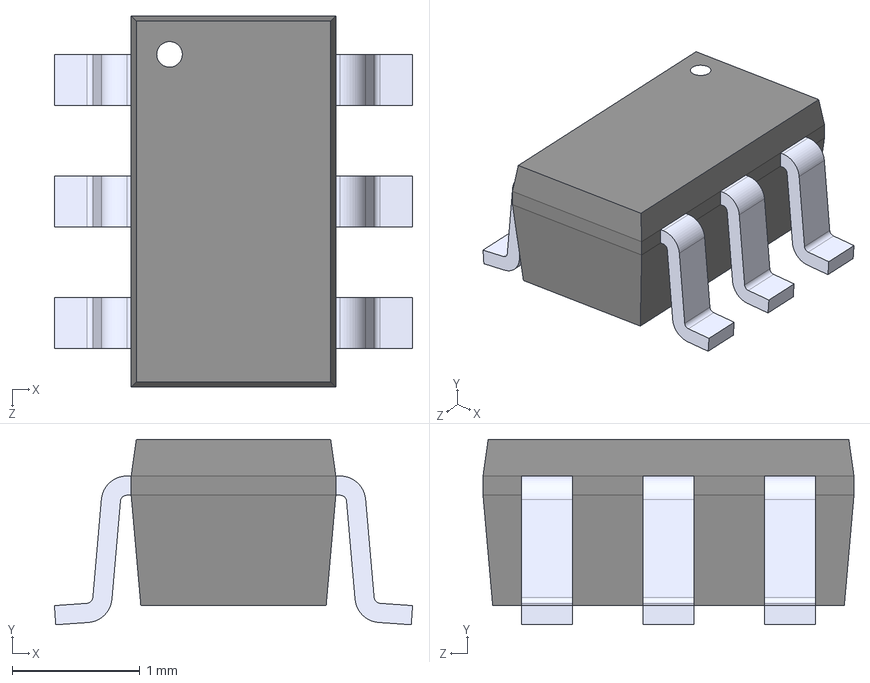
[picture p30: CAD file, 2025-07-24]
pcb/FOX-JACK_EXT_BOARD_TOP/3dmodules/FS8205.step
2.80 x 1.45 x 2.90 mm

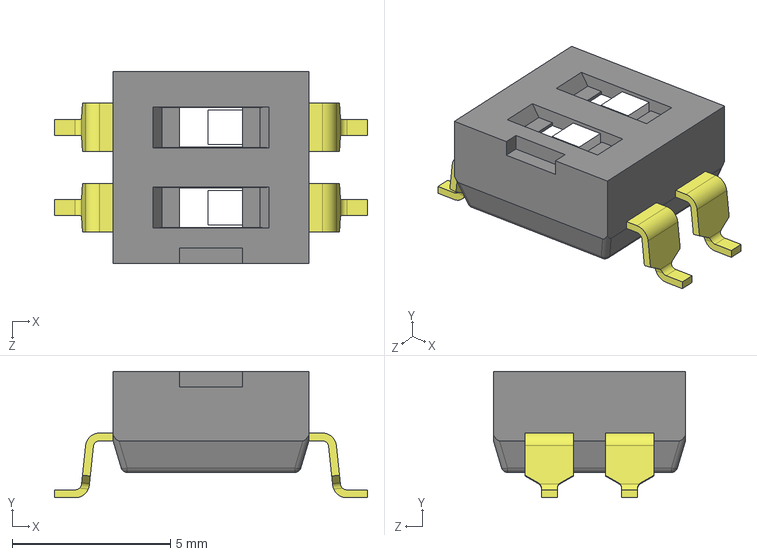
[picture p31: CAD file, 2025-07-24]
pcb/FOX-JACK_EXT_BOARD_TOP/3dmodules/DS04-254-2-02BK-SMT.step
9.90 x 4.00 x 6.08 mm

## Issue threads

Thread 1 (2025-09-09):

NetExec

Sh7yk, 2025-09-09:
Hello! Great project!
It would be great except NMAP to NetExec to the arsenal of the device to make useful loads for it too. It will be useful for reconnaissance in hell and collecting low-hanging fruits

KaliAssistant, 2025-09-13:
Okay, I'll take a look. But the biggest problem is that buildroot is based on the ulibc toolchain, not the glibc toolchain.
If I change the rootfs to use the glibc toolchain, it means you can run any Linux distribution on Fox-Jack, but it would be a lot of work.

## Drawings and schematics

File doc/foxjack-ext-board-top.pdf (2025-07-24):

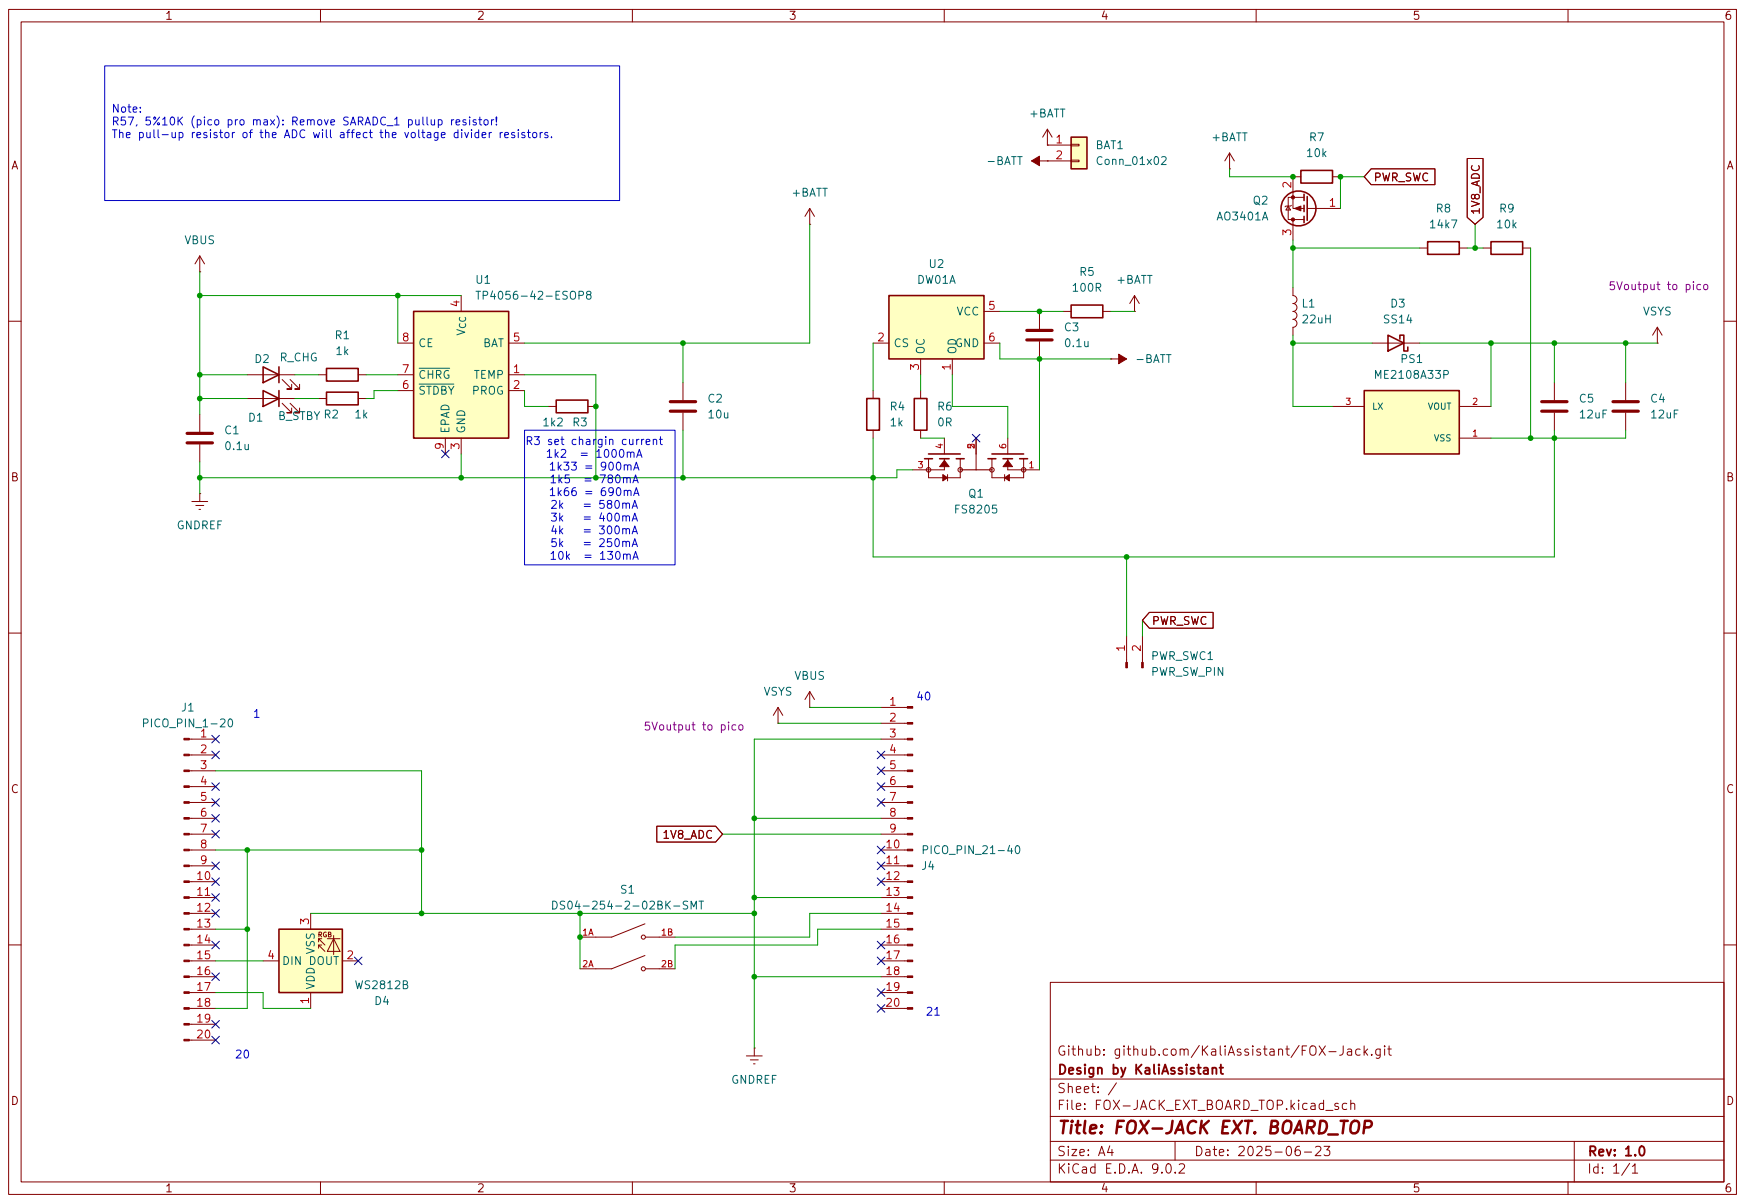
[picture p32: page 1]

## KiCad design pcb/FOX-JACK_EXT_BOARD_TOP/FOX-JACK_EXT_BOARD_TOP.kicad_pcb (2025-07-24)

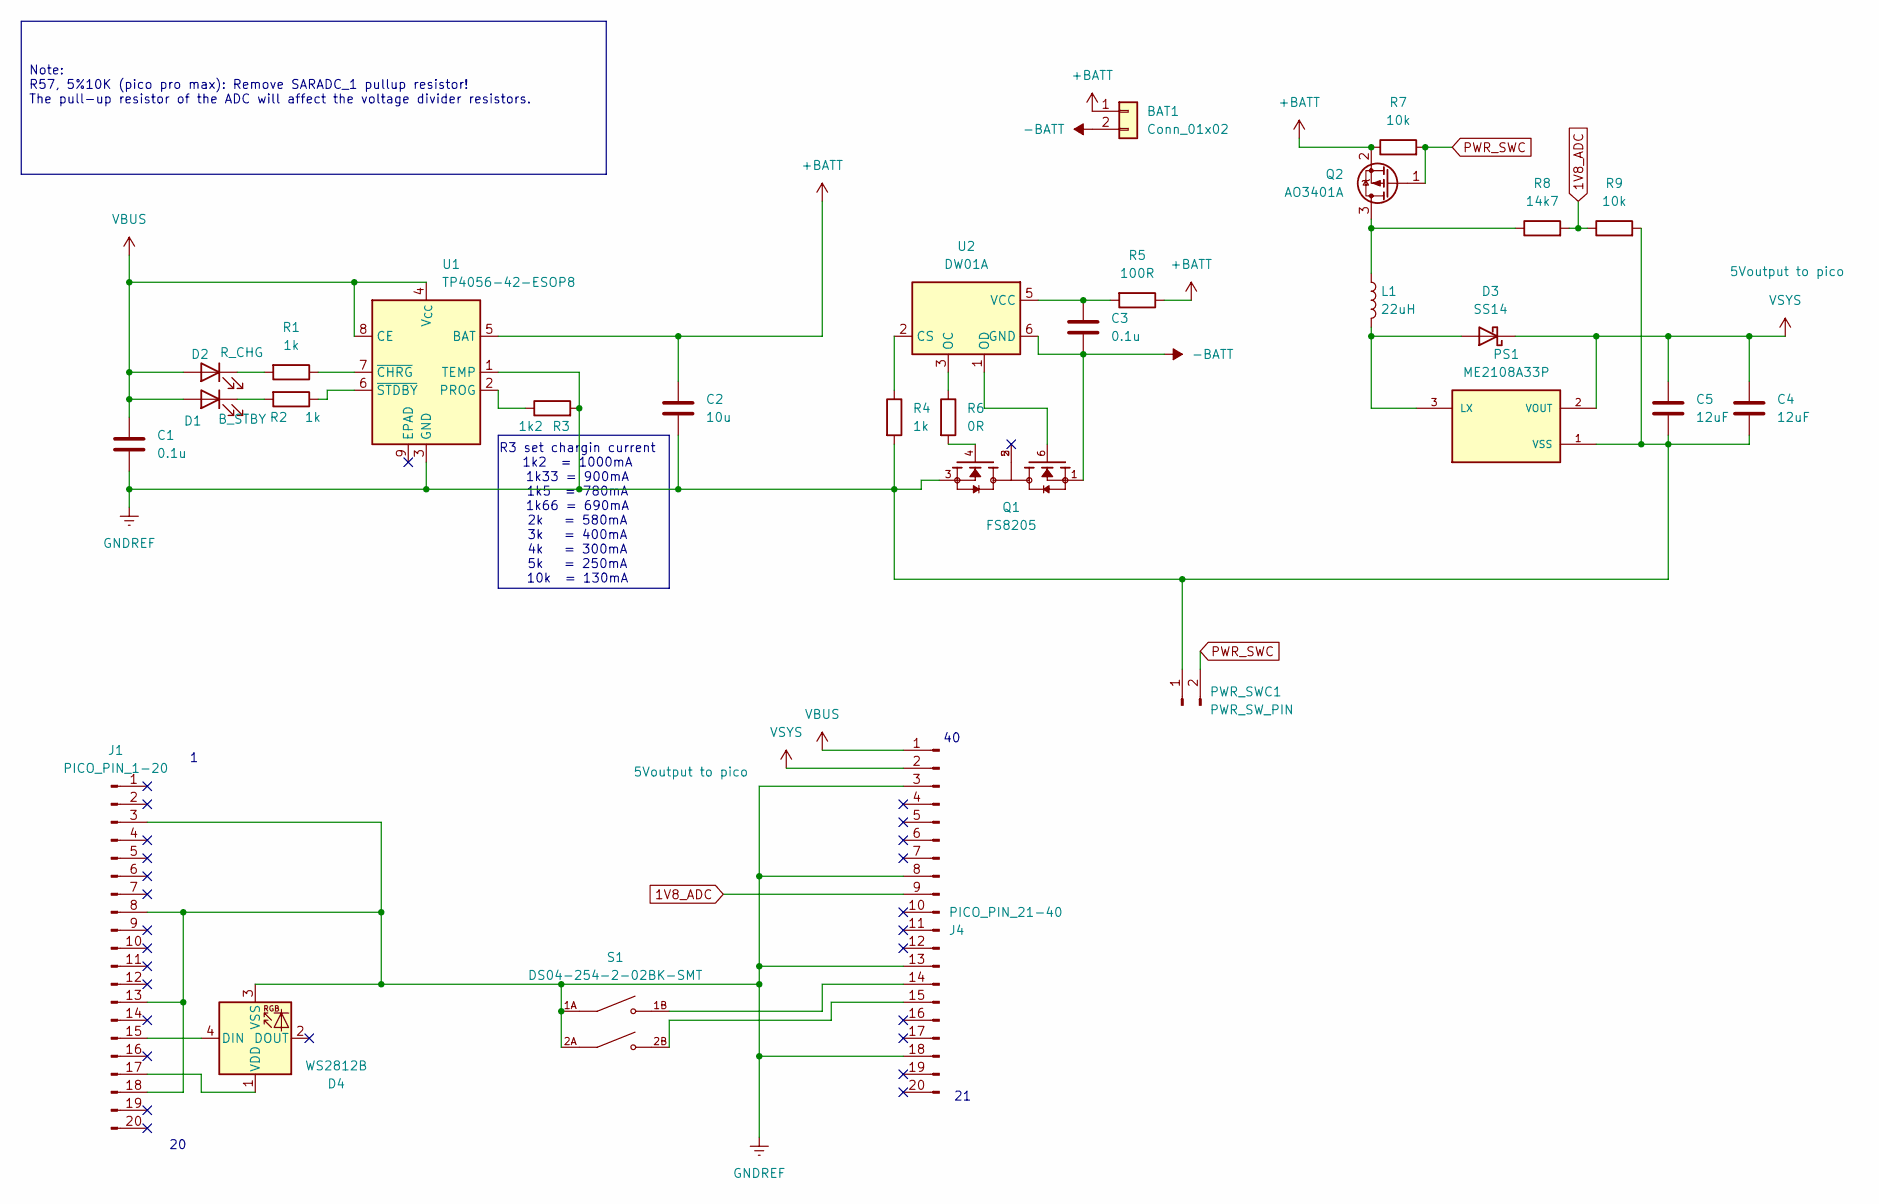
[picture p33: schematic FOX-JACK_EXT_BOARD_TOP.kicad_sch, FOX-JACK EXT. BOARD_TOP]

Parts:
BAT1: Conn_01x02; BAT_PAD
C1, C3: 0.1u; C_0402_1005Metric
C2: 10u; C_0603_1608Metric
C4, C5: 12uF; C_1210_3225Metric
D1: B_STBY; LED_0603_1608Metric
D2: R_CHG; LED_0603_1608Metric
D3: SS14; D_SMA
D4: WS2812B; LED_WS2812B_PLCC4_5.0x5.0mm_P3.2mm
J1: PICO_PIN_1-20; PinHeader_1x20_P2.54mm_Vertical
J4: PICO_PIN_21-40; PinHeader_1x20_P2.54mm_Vertical
L1: 22uH; L_Changjiang_FNR3015S
PS1: ME2108A33P; CONV_ME2108A33P; PARTREV V10.0
PWR_SWC1: PWR_SW_PIN; PinHeader_1x02_P2.54mm_Vertical
Q1: FS8205; SOT95P280X145-6N; PARTREV 1.9
Q2: AO3401A; SOT-23
R1, R2: 1k; R_0402_1005Metric
R3: 1k2; LED_0402_1005Metric
R4: 1k; R_0603_1608Metric
R5: 100R; R_0805_2012Metric
R6: 0R; LED_0805_2012Metric
R7, R9: 10k; R_0402_1005Metric
R8: 14k7; R_0402_1005Metric
S1: DS04-254-2-02BK-SMT; SW_DS04-254-2-02BK-SMT; PARTREV V0.0
U1: TP4056-42-ESOP8; SOIC-8-1EP_3.9x4.9mm_P1.27mm_EP2.41x3.3mm_ThermalVias
U2: DW01A; SOT-23-6

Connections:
1V8_ADC: J4.9, R8.2, R9.1
+BATT: BAT1.1, C2.1, Q2.2 (S), R5.1, R7.1, U1.5 (BAT)
-BATT: BAT1.2, C3.2, Q1.1, U2.6 (GND)
GNDREF: C1.2, C2.2, C4.2, C5.2, D4.3 (VSS), J1.3, J1.8, J1.13, J1.18, J4.3, J4.8, J4.13, J4.18, PS1.1 (VSS), PWR_SWC1.1, Q1.3, R3.2, R4.2, R9.2, S1.1A, S1.2A, U1.1 (TEMP), U1.3 (GND)
unnamed: D1.1 (K), R2.2
unnamed: D2.1 (K), R1.2
unnamed: D3.2 (A), L1.2, PS1.3 (LX)
unnamed: D4.4 (DIN), J1.15
unnamed: D4.1 (VDD), J1.17
unnamed: J4.14, S1.1B
unnamed: J4.15, S1.2B
unnamed: Q1.4, R6.2
unnamed: L1.1, Q2.3 (D), R8.1
unnamed: R3.1, U1.2 (PROG)
unnamed: R1.1, U1.7 (~CHRG)
unnamed: R2.1, U1.6 (~STDBY)
unnamed: R4.1, U2.2 (CS)
unnamed: R6.1, U2.3 (OC)
unnamed: Q1.6, U2.1 (OD)
unnamed: C3.1, R5.2, U2.5 (VCC)
PWR_SWC: PWR_SWC1.2, Q2.1 (G), R7.2
VBUS: C1.1, D1.2 (A), D2.2 (A), J4.1, U1.4 (V_{CC}), U1.8 (CE)
VSYS: C4.1, C5.1, D3.1 (K), J4.2, PS1.2 (VOUT)

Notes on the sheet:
R3 set chargin current 1k2 = 1000mA 1k33 = 900mA 1k5 = 780mA 1k66 = 690mA 2k = 580mA 3k = 400mA 4k = 300mA 5k = 250mA 10k = 130mA
Note: R57, 5%10K (pico pro max): Remove SARADC_1 pullup resistor! The pull-up resistor of the ADC will affect the voltage divider resistors.

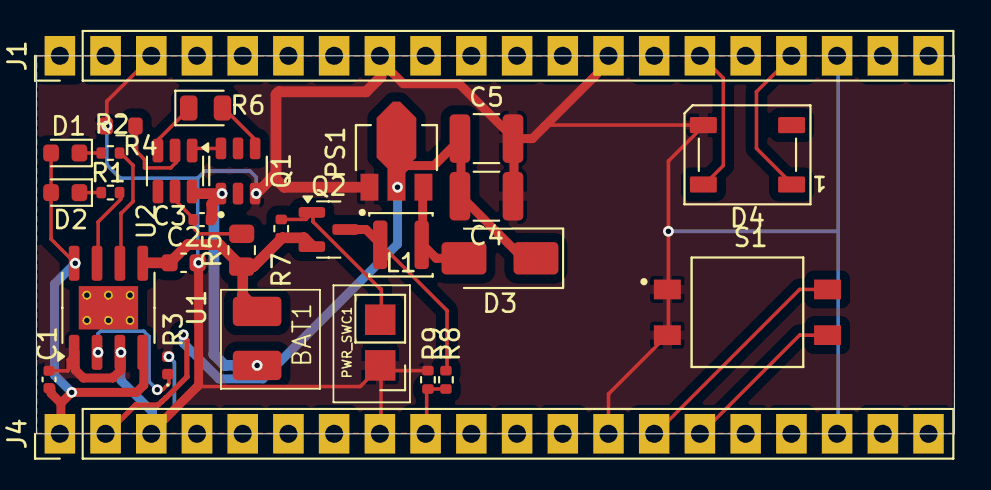
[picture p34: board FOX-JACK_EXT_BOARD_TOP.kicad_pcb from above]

Board: 2 copper layers, 51.0 x 21.0 mm, 29 parts (0 on the bottom side), 23 nets.

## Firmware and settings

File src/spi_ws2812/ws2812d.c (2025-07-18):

#include <stdio.h>
#include <stdint.h>
#include <fcntl.h>
#include <linux/spi/spidev.h>
#include <sys/ioctl.h>
#include <linux/gpio.h>
#include <unistd.h>
#include <string.h>
#include <stdlib.h>
#include <sys/mman.h>
#include <time.h>
#include <sys/stat.h>
#include <sys/types.h>
#include <signal.h>
#include <errno.h>
#include <sys/file.h>  // for flock()


#define SPI_DEV "/dev/spidev0.0"
#define SPI_SPEED 3300000  // 3.3 MHz
#define SPI_BITS 8
#define SHM_PATH "/dev/shm/led_rgb"
#define DELAY_US 2000
#define POWER_PIN_GPIOCHIP "/dev/gpiochip2"
#define POWER_PIN_GPIOCHIP_BASE 64
#define POWER_PIN 72  // 72 --> gpio2_b0_d (17)

int POWER_PIN_GPIO_LINE_OFFEST = (POWER_PIN - POWER_PIN_GPIOCHIP_BASE);

// Lookup table for WS2812 1-bit -> 3 SPI bits
const uint8_t ws2812_lookup[2] = { 0b100, 0b110 };  // 0 = 100, 1 = 110


static volatile int keep_running = 1;

void handle_sigint(int sig) {
    (void)sig;
    keep_running = 0;
}


uint8_t *init_led_shm() {
    int fd = open(SHM_PATH, O_RDWR | O_CREAT, 0666);
    if (fd < 0) {
        perror("open/create shared memory");
        return NULL;
    }

    // Check file size, resize if needed
    struct stat st;
    if (fstat(fd, &st) < 0) {
        perror("fstat");
        close(fd);
        return NULL;
    }

    if (st.st_size < 3) {
        if (ftruncate(fd, 3) < 0) {
            perror("ftruncate");
            close(fd);
            return NULL;
        }
        // Optional: initialize to 0
        write(fd, "\x00\x00\x00", 3);
        lseek(fd, 0, SEEK_SET);
    }

    // mmap
    uint8_t *rgb = mmap(NULL, 3, PROT_READ | PROT_WRITE, MAP_SHARED, fd, 0);
    if (rgb == MAP_FAILED) {
        perror("mmap");
        close(fd);
        return NULL;
    }

    close(fd);
    return rgb;
}

// Encode a single WS2812 byte (8 bits) into 24 SPI bits
void encode_byte(uint8_t byte, uint8_t *spi_bits, int *bit_index) {
    for (int i = 7; i >= 0; i--) {
        uint8_t bit = (byte >> i) & 1;
        uint8_t pattern = ws2812_lookup[bit];
        for (int j = 2; j >= 0; j--) {
            int idx = *bit_index / 8;
            int shift = 7 - (*bit_index % 8);
            spi_bits[idx] |= ((pattern >> j) & 1) << shift;
            (*bit_index)++;
        }
    }
}


void send_led(int spi_fd, uint8_t r, uint8_t g, uint8_t b) {
    uint8_t spi_data[9] = {0};  // 3 colors * 8 bits * 3 = 72 bits = 9 bytes
    int bit_index = 0;

    encode_byte(g, spi_data, &bit_index);  // GRB order
    encode_byte(r, spi_data, &bit_index);
    encode_byte(b, spi_data, &bit_index);

    struct spi_ioc_transfer tr = {
        .tx_buf = (unsigned long)spi_data,
        .len = sizeof(spi_data),
        .speed_hz = SPI_SPEED,
        .bits_per_word = SPI_BITS,
    };

    ioctl(spi_fd, SPI_IOC_MESSAGE(1), &tr);
    usleep(80);  // WS2812 latch (>50us)
}

int main() {
    int lock_fd = open("/var/run/ws2812d.lock", O_CREAT | O_RDWR, 0644);
    if (lock_fd < 0) {
        perror("open lock file");
        return 1;
    }

    // Try to acquire exclusive lock (non-blocking)
    if (flock(lock_fd, LOCK_EX | LOCK_NB) < 0) {
        if (errno == EWOULDBLOCK) {
            fprintf(stderr, "Another instance is already running.\n");
            return 1;
        } else {
            perror("flock");
            return 1;
        }
    }

    

    pid_t pid = fork();
    if (pid < 0) {
        perror("fork failed");
        return 1;
    }
    if (pid > 0) {
        // Parent exits, child continues
        return 0;
    }

    // Become session leader
    if (setsid() < 0) {
        perror("setsid failed");
        return 1;
    }
    
    // Optional: Write PID to file
    ftruncate(lock_fd, 0);
    dprintf(lock_fd, "%d\n", getpid());

    // Redirect stdio to /dev/null
    close(0); close(1); close(2);
    open("/dev/null", O_RDONLY);  // stdin
    open("/dev/null", O_WRONLY);  // stdout
    open("/dev/null", O_RDWR);    // stderr

    // Optionally change working dir
    chdir("/");
    
    uint8_t *rgb = init_led_shm();
    if (!rgb) return 1;

    int chip_fd = open(POWER_PIN_GPIOCHIP, O_RDONLY);
    if (chip_fd < 0) {
        perror("open gpiochip");
        return 1;
    }

    struct gpiohandle_request req;
    memset(&req, 0, sizeof(req));
    req.lineoffsets[0] = POWER_PIN_GPIO_LINE_OFFEST;              // GPIO line offset in the chip
    req.flags = GPIOHANDLE_REQUEST_OUTPUT;
    req.default_values[0] = 0;
    req.lines = 1;

    if (ioctl(chip_fd, GPIO_GET_LINEHANDLE_IOCTL, &req) < 0) {
        perror("GPIO_GET_LINEHANDLE_IOCTL");
        close(chip_fd);
        return 1;
    }

    close(chip_fd);  
    
    signal(SIGINT, handle_sigint);

    struct gpiohandle_data g_data = { .values[0] = 1 }; //POWER ON

    if (ioctl(req.fd, GPIOHANDLE_SET_LINE_VALUES_IOCTL, &g_data) < 0) {
        perror("GPIOHANDLE_SET_LINE_VALUES_IOCTL");
        close(req.fd);
        return 1;
    }


    int spi_fd = open(SPI_DEV, O_WRONLY);
    if (spi_fd < 0) {
        perror("open SPI");
        return 1;
    }

    // Setup SPI
    uint8_t mode = SPI_MODE_0;
    ioctl(spi_fd, SPI_IOC_WR_MODE, &mode);
    ioctl(spi_fd, SPI_IOC_WR_BITS_PER_WORD, &(uint8_t){SPI_BITS});
    ioctl(spi_fd, SPI_IOC_WR_MAX_SPEED_HZ, &(uint32_t){SPI_SPEED});

    // Background loop
    uint8_t last_rgb[3] = {255, 255, 255};  // force initial update

    while (keep_running) {
        if (memcmp(rgb, last_rgb, 3) != 0) {
            memcpy(last_rgb, rgb, 3);
            send_led(spi_fd, rgb[0], rgb[1], rgb[2]);
        }

        usleep(DELAY_US);  // 10ms polling (can be lower, like 2ms)
    }

    munmap(rgb, 3);
    close(spi_fd);
  
    g_data.values[0] = 0; //POWER OFF
    if (ioctl(req.fd, GPIOHANDLE_SET_LINE_VALUES_IOCTL, &g_data) < 0) {
        perror("GPIOHANDLE_SET_LINE_VALUES_IOCTL");
        close(req.fd);
        return 1;
    }

    close(req.fd);

    return 0;
}

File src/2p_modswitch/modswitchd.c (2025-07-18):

#include <stdio.h>
#include <stdint.h>
#include <fcntl.h>
#include <unistd.h>
#include <string.h>
#include <stdlib.h>
#include <sys/mman.h>
#include <time.h>
#include <sys/stat.h>
#include <sys/types.h>
#include <signal.h>
#include <errno.h>
#include <linux/gpio.h>
#include <sys/ioctl.h>
#include <sys/file.h>  // for flock()


#define SHM_PATH "/dev/shm/modswitch"
#define DELAY_US 10000
#define GPIOCHIP "/dev/gpiochip2"
#define GPIOCHIP_BASE 64
#define SW1_PIN 67  // 67 --> gpio2_a3_d (27)
#define SW2_PIN 66  // 66 --> gpio2_a2_d (26)
#define GPIO_PULL_MODE 1  // 1 = PULL_UP; 0 = PULL_DOWN
int GPIO_LINE_OFFSETS[2] = {(SW1_PIN - GPIOCHIP_BASE), (SW2_PIN - GPIOCHIP_BASE)};  // offset within chip, e.g., GPIO66, GPIO67 if base is 64



static volatile int keep_running = 1;

void handle_sig_kill(int sig) {
    (void)sig;
    keep_running = 0;
}

uint8_t *init_sw_shm() {
    int fd = open(SHM_PATH, O_RDWR | O_CREAT, 0644);
    if (fd < 0) {
        perror("open/create shared memory");
        return NULL;
    }
    
    struct stat st;
    if (fstat(fd, &st) < 0) {
        perror("fstat");
        close(fd);
        return NULL;
    }

    if (st.st_size < 1) {
        if (ftruncate(fd, 1) < 0) {
            perror("ftruncate");
            close(fd);
            return NULL;
        }
        // Optional: initialize to 0
        write(fd, "\x30", 1);
        lseek(fd, 0, SEEK_SET);
    }

    // mmap
    uint8_t *modswitch = mmap(NULL, 1, PROT_READ | PROT_WRITE, MAP_SHARED, fd, 0);
    if (modswitch == MAP_FAILED) {
        perror("mmap");
        close(fd);
        return NULL;
    }
    
    close(fd);
    return modswitch;
}

int main() {
    int lock_fd = open("/var/run/modswitchd.lock", O_CREAT | O_RDWR, 0644);
    if (lock_fd < 0) {
        perror("open lock file");
        return 1;
    }

    // Try to acquire exclusive lock (non-blocking)
    if (flock(lock_fd, LOCK_EX | LOCK_NB) < 0) {
        if (errno == EWOULDBLOCK) {
            fprintf(stderr, "Another instance is already running.\n");
            return 1;
        } else {
            perror("flock");
            return 1;
        }
    }

    pid_t pid = fork();
    if (pid < 0) {
        perror("fork failed");
        return 1;
    }
    if (pid > 0) {
        // Parent exits, child continues
        return 0;
    }
    if (setsid() < 0) {
        perror("setsid failed");
        return 1;
    }
    
    // Optional: Write PID to file
    ftruncate(lock_fd, 0);
    dprintf(lock_fd, "%d\n", getpid());


    // Redirect stdio to /dev/null
    close(0); close(1); close(2);
    open("/dev/null", O_RDONLY);  // stdin
    open("/dev/null", O_WRONLY);  // stdout
    open("/dev/null", O_RDWR);    // stderr

    // Optionally change working dir
    chdir("/");

    
    uint8_t *modswitch = init_sw_shm();
    if (!modswitch) return 1;

    // Open the gpiochip device
    int chip_fd = open(GPIOCHIP, O_RDONLY);
    if (chip_fd < 0) {
        perror("open gpiochip");
        return 1;
    }
  
    struct gpiohandle_request req;
    memset(&req, 0, sizeof(req));

    req.lineoffsets[0] = GPIO_LINE_OFFSETS[0];
    req.lineoffsets[1] = GPIO_LINE_OFFSETS[1];
    req.lines = 2;
    req.flags = GPIOHANDLE_REQUEST_INPUT;

    if (ioctl(chip_fd, GPIO_GET_LINEHANDLE_IOCTL, &req) < 0) {
        perror("GPIO_GET_LINEHANDLE_IOCTL");
        close(chip_fd);
        return 1;
    }

    close(chip_fd); // no longer needed
    
    signal(SIGINT, handle_sig_kill);
    signal(SIGTERM, handle_sig_kill);

    while (keep_running) {
        struct gpiohandle_data data;
        if (ioctl(req.fd, GPIOHANDLE_GET_LINE_VALUES_IOCTL, &data) < 0) {
            perror("GPIOHANDLE_GET_LINE_VALUES_IOCTL");
            break;
        }

        int sw1 = data.values[0];
        int sw2 = data.values[1];

        // Combine into a value 0–3
        uint8_t combined = (((GPIO_PULL_MODE ? !sw2 : sw2) << 1) | (GPIO_PULL_MODE ? !sw1 : sw1)) & 0x03;

        // Write to shared memory
        *modswitch = combined + '0'; // ascii
        usleep(DELAY_US);
    }

    munmap(modswitch, 1);
    close(req.fd);
    return 0;
}

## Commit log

2025-06-27 add 3dp cases
    [LUCKFOX_FOXJACK_BTM.stl, LUCKFOX_FOXJACK_TOP.stl]
2025-07-21 add battery monitor support
2025-07-24 payloads and README
    [DS04-254-2-02BK-SMT.step, FOX-JACK_EXT_BOARD_BOM.csv, FOX-JACK_EXT_BOARD_MID.kicad_pcb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]
2025-07-24 update 3dp cases
    [LUCKFOX_FOXJACK_BTM.stl, LUCKFOX_FOXJACK_TOP.stl]
2025-07-26 UPDATE PCB
    [BOM.csv, FOX-JACK_EXT_BOARD_BOM.csv, FOX-JACK_EXT_BOARD_TOP.kicad_sch]
2025-07-31 UPDATE #DP case
    [LUCKFOX_FOXJACK_BTM.stl]
2025-12-11 Update Amazon link for 302040 Lipo battery
